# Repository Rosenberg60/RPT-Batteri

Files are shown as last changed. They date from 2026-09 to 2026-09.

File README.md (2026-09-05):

# RPT & Rosen Batterimonitor med Waveshare ESP32-S3-Touch-LCD-7 (Rev 1.2)

Dette projekt er en dedikeret CAN-bus monitor, telemetrilogger og web-dashboard for et **51,2V LiFePO₄ hybridsystem: Rosen 200Ah Master + RPT Tower 300Ah (Samlet 501 Ah / 25,6 kWh)** tilsluttet en **Deye SUN-12K-SG05LP3-EU** hybridinverter.

Systemet kører på en **Waveshare ESP32-S3-Touch-LCD-7 (Rev 1.2)** med 7,0" IPS RGB-skærm (800 × 480 capacitive touch), MicroSD-blackbox-logger og indbygget WiFi-webserver.

---

## 1. Systemstatus & Funktioner

* **Multi-Side Touch Dashboard (800 × 480 IPS)**:
  * **Side 1 (Hovedoversigt)**: Store hero-kort for **SOC (%)**, **Storage Power (kW)**, **Bank Spænding (V)** og **Total & Peak Strøm (A)** (med automatisk skalering for afladestrømme $> 100\text{ A}$). Statusfelter for Min/Max cellespænding, cell delta (mV), ladestatus, invertergrænser og intern 3,7V LiPo backup-batteristatus (`Lipo Bat: x.xV (xx%)`).
  * **Side 2 (Cell Diagnostics 32S)**: Komplet 32-celle visning med 16S Rosen Master og 16S RPT Tower. Dynamisk farvekodning (grøn/gul/rød/blå) og flimmerfri differential-opdatering.
  * **Side 3 (CAN Scanner)**: Real-tids tabel over alle modtagne CAN ID'er, frekvens, antal, payload og live frame-terminal.
  * **Touch Styring**: Touch er eksklusivt afgrænset til de 3 navigationsknapper i bunden ($Y \ge 420$) for at forhindre utilsigtede sideskift.
* **Integreret Web-Interface (WiFi)**:
  * Responsivt web-dashboard tilgåeligt via `http://rpt-batteri.local` eller ESP32's IP-adresse.
  * 4x forhøjede spændingssøjler for maksimal visualisering af cellebalance i 16S pack.
  * REST API endpoints: `/api/data` og `/api/scanner` med JSON telemetri.
* **Batteri Backup Monitor**:
  * Analog måling af tilsluttet 3,7V LiPo-batteri via GPIO 4 (ADC) med SOC estimering.
* **MicroSD Blackbox Logging**:
  * Automatisk logning af samtlige rå CAN-rammer til MicroSD i standard CSV-format (`/can_log_XXX.csv`).
* **Høj Stabilitet & Multi-Kerne Arkitektur**:
  * Dedikerede FreeRTOS tasks på Kerne 0 (CAN + Logger + WebServer) og Kerne 1 (UI Display Rendering).
  * Ikke-blokerende CAN queue drain, FreeRTOS mutexes i stedet for spinlocks, og beskyttelse mod Task Watchdog timeouts.

---

## 2. Systemarkitektur & Forbindelser

Inverteren (**Deye SUN-12K-SG05LP3-EU**) og batterierne (**Rosen 200Ah Master** og **RPT Tower 300Ah**) kommunikerer via batteriets BMS CAN-bus:

```text
+-----------------------------------------------------------------------------------------+
|                                    SYSTEMOVERSIGT                                       |
|                                                                                         |
|   +-----------------------+              CAN Bus            +-----------------------+   |
|   |  Deye SUN-12K         |<===============================>|  Rosen Master 200Ah   |   |
|   |  Inverter             |   (Eksisterende bus)            |  + RPT Tower 300Ah    |   |
|   +-----------------------+                                 +-----------+-----------+   |
|                                                                         |               |
|                                                     CAN-Port (RJ45)     |               |
|                                                     Pin 4 = CAN-H       |               |
|                                                     Pin 5 = CAN-L       |               |
|                                                                         v               |
|                                                             +-----------------------+   |
|                                                             |  Waveshare 7" Rev1.2  |   |
|                                                             |  ESP32-S3 (800x480)   |   |
|                                                             +-----------------------+   |
+-----------------------------------------------------------------------------------------+
```

---

## 3. Hardwareguide for Waveshare ESP32-S3-Touch-LCD-7 (Rev 1.2)

### Fysisk placering af stik og jumpere:

1. **Bunden af printet (Hvide JST-PH2.0 stik fra venstre mod højre)**:
   * `Battery` (2-ben): `-` (Venstre, GND), `+` (Højre, 3,7V LiPo/Li-ion).
   * `RS-485` (2-ben): `A`, `B`.
   * `I2C` (4-ben): **`VCC`**, **`GND`**, `SDA`, `SCL`.
   * `CAN` (2-ben): **`L`** (Venstre, CAN-L), **`H`** (Højre, CAN-H).
   * `Sensor AD` (3-ben): `3V3`, `GND`, `AD` (GPIO 4 ADC).
2. **Venstre side af printet (Gule jumpere)**:
   * Øverste gule jumper: `RS-485 120R / NC`.
   * Nederste gule jumper: **`CAN 120R / NC`** *(Skal sidde på `120R`)*.
3. **Midt-højre på printet (Sort 3-bens jumper)**:
   * Jumper mærket **`I2C 3V3 / 5V`** *(Sættes på `5V` hvis kortet forsynes via I2C-stikket)*.
4. **Toppen af printet**:
   * Venstre USB Type-C: `USB` (Native ESP32-S3 USB).
   * Højre USB Type-C: `UART1` (Onboard CH343 USB-to-UART programmeringsport).
   * MicroSD-kortlæser (TF-card).

---

## 4. CAN-forbindelse & Terminering

Fra et standard RJ45 netværkskabel forbundet til batteriets CAN-port:
* **Pin 4 (Blå leder)** $\rightarrow$ Forbindes til **`H`** (CAN-H) på Waveshare CAN-stikket.
* **Pin 5 (Blå/Hvid leder)** $\rightarrow$ Forbindes til **`L`** (CAN-L) på Waveshare CAN-stikket.
* Jumperen **`CAN 120R / NC`** skal sidde i **`120R`** position.

---

## 5. Softwarearkitektur

Kildekoden er struktureret modulært i `RPT_Batteri_Monitor/`:

```text
├── platformio.ini              # PlatformIO konfiguration (bygger direkte fra sketch-mappen)
├── RPT_Batteri_Monitor/        # [Arduino Sketch Mappe] - Åbnes i Arduino IDE eller PlatformIO
│   ├── RPT_Batteri_Monitor.ino # Hoved-sketch (setup, loop, task scheduling, CAN drain)
│   ├── board_config.h          # Pin-definitioner (CAN TX=20, RX=19, CH422G, I2C, SPI)
│   ├── board_battery.h/.cpp    # 3,7V LiPo spændingsmåling via ADC (GPIO 4)
│   ├── battery_data.h          # Komplette datastrukturer for 32S telemetri, limits & statistik
│   ├── can_receiver.h/.cpp     # TWAI driver med ringbuffer og alert-drevet RX
│   ├── deye_bms_decoder.h/.cpp # Deye/Rosen/RPT CAN protokol-dekoder med FreeRTOS mutex
│   ├── sd_logger.h/.cpp        # MicroSD CSV logger (flush hvert 1000ms / 50 rammer)
│   ├── ui.h/.cpp               # 800x480 PSRAM-framebuffer rendering, 3-siders UI & touch
│   ├── web_server.h/.cpp       # WiFi webserver, live dashboard og REST JSON endpoints
│   └── wifi_config.h           # WiFi SSID, adgangskode og værtsnavn
└── docs/
    ├── ESP32-S3-Touch-LCD-7-Sch.pdf   # Waveshare skematik
    └── waveshare_7_board_rev1.2.jpg   # Foto af printet med stikforklaringer
```

---

## 6. Kompilering & Upload

### Mulighed A: PlatformIO (Anbefalet)
1. Forbind kortet til PC via **UART1** USB-C porten (højre port).
2. Byg og upload med én kommando:
   ```bash
   pio run -t upload
   ```
3. Åbn seriel monitor ved 115200 baud:
   ```bash
   pio device monitor
   ```

### Mulighed B: Arduino IDE
1. Åbn filen: **`RPT_Batteri_Monitor/RPT_Batteri_Monitor.ino`** i Arduino IDE.
2. Vælg board: **ESP32S3 Dev Module**.
3. Under **Tools** vælges:
   * **Flash Size**: `16MB (128Mb)`
   * **Partition Scheme**: `16M Flash (3MB APP/9.9MB FATFS)` eller `Default 16MB`
   * **PSRAM**: `OPI PSRAM`
   * **CPU Frequency**: `240MHz`
   * **Upload Speed**: `921600`
   * **USB CDC On Boot**: `Disabled` (eller `Enabled`)
   * **Port**: Vælg COM-porten for USB-TO-UART forbindelsen (CH343 på UART1).
4. Klik på **Upload**.

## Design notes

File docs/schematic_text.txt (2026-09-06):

--- PAGE 1 ---
1
1
2
2
3
3
4
4
5
5
6
6
D D
C C
B B
A A
aveshareW
GND 41
GND 40
IO1 39
IO2 38
TXD0 37
RXD0 36
IO42 35
IO41 34
IO40 33
IO39 32
IO38 31
IO37 30
IO36 29
IO35 28
IO0 27
IO4526 IO4825 IO4724 IO2123 IO1422 IO1321 IO1220 IO1119 IO1018 IO917 IO4616 IO315
IO2014 IO1913 IO812 IO1811 IO1710 IO169 IO158 IO77 IO66 IO55 IO44 EN3 3V32 GND1
U8 ESP32-S3-WROOM-1-N8R8
3V3 GND
R1061KΩ A K
Red
PWR1
GND
3V3
IO3
GND
3V3
IO45
GND
3V3
IO46
Strapping Pins
I2C_VCC
G11
S22
G23 D2 4S1 5D1 6
M1
NDC7002N
D_SDA
SDA
3V3
I2C_VCC
D_SCL
R113
4.7K
SCL
3V3
R109
4.7K
R108
4.7K
R110
4.7K
GND
GND
RESET
3V3
IO4
IO5
IO6
IO7'
IO8
IO9
IO10
IO11
IO12 IO13
IO14
IO15
IO16
IO17
IO18
IO21
IO38
IO39
IO40
IO41
IO42
IO45
IO46
IO47
IO48
IO0
IO1
IO2
IO3
TX0
RX0
R107499R
ESP_RXD
GND
C46
100nF
GND
3V3
C45
10uF
ESP_USB_N
ESP_USB_P
ESP_TXD
1
2
3
H2
I2C_VCC
5V
3V3 I2C_VCC
GND
D_SDA
D_SCL
VCC
GND
SDA
SCL
C8
10uF/16V
C10
10uF/16V
GND
5V 3V3
C9
100nF
C11
100nF
G1
Vo2
Vi3
U5 SGM2212-3.3XKC3G/TR
GND A1/B12
VBUS A4/B9
CC1 A5
DN2 B7
DP1 A6
DN1 A7
SBU1 A8
GND A12/B1VBUS A9/B4CC2 B5
DP2 B6
SBU2 B8
GND MTB
Type_C1
USBD_N
USBD_P
USBD_N
USBD_P
GND VBUS
DCC1
DCC2
R2 5.1K
R3 5.1K
DCC1
DCC2 GND
GND
GND
CH_RXD
CH_TXD
VBUS
3V3
3V3
VBUS
KEY
K1
GND
R93 10K
3V3
DTR
RTS
IO0
DTR
RTS
3
1
2
Q9
SS8050
R4
10K
R29
10K
RESET
3
1
2
Q6
SS8050
C43 100nF
KEY
K2
GND
R100 10K
3V3
RESET
IO0
USB_P
USB_N
USBD_N
USBD_P
R5 0R
R10 0R
USB_N
USB_P
close to ENDPOINT
USBH_N
USBH_P
R65 0R
R66 0R
close to ENDPOINT
C30 100nF
GND
R8910K
R9010K
R9110K
GND
3V3
3V3
3V3
C42 10uF
R8810K
MOSI
SCK
MISO
SDCS
close to SD1
VBUS
R30 0.56Ω
C5
10uF/16V
GND
R31
4.7K
A KGreen
Led1
A K
RedLed2
R64
1.2K
GND GND
1 2 D12
1N5819
L2
4.7uH  4*4*1.8 1.7A
GND
C6
10uF/16V
GND
C7
10uF/16V
GND
VBAT
5V
C3
100nF
GND
1 2D11 1N5819
R44 0.56Ω
C4
100uF
Battery
USB  to UART
RO1
RE2
DE3
DI4 GND 5
A 6
B 7
VCC 8
U6
SP3485EN
5V
GND
GND
RS485_TX-
R82
10K
5V
C16 100nF
R73
10K
D15
SMAJ12CA
GND
RS485_TX+
1F1
1
F2
R70
120R
A1
COM2
B3
J4
C28
NC
C29
NC
A1
B1
EARTH
EARTH
S1
R76
4.7K
GND
R81
4.7K
3V3
R78
4.7K
R74
4.7K
GND
EARTH GND
R86 0R
RS485_TX-
RS485_TX+
RS485_TXD
RS485
USB
KEY
SD-CARD
CAN
GND
D8 LESD8LH5.0CT5G
D9
LESD8LH5.0CT5G
GND
GND
GND
D13 LESD8LH5.0CT5G
D14
LESD8LH5.0CT5G
GND
GND
D21
CD/D32
CMD3
VDD4
CLK5
VSS6
D07
D18
CD 9
GND10
SD1
GND
VOUT 1
CHRG2
STDBY4
PROG3
VCC5
BAT 6
GND0
LX 8
GND7
U4
CS8501
GND VBAT
11
22
00
J3
GND
R95
NC
R96
NC
R97
NC
R103
NC
R104
10K
R105
10K
C47
1uF
C48
100nF
GND
SDA
SCL
GND
3V3
EXIO2
EXIO1
EXIO3EXIO4
Sensor AD
IO19
IO20
D16
SMAJ12CA
D17
SMAJ12CA
VIO1
GND2
VDD53
TXD4
RXD5
V36
UD+7
UD-8 VBUS 9ACT# 10DCD 11DTRTNOW 12RTS 13DSR 14CTS 15RI 16
EP 0
U1
CH343P
默认贴3V3
High
Low
IO41
IO52
IO63
IO74
SCL5
SDA6
GND7
OC08 OC1 9OC2 10OC3 11IO0 12IO1 13VCC 14IO2 15IO3 16
U10
CH422G
TXD1
GND2
VCC3
RXD4 VIO 5CANL 6CANH 7S 8
U7
TJA1051T/3/1J
CANTX
CANRX
CANH
CANL
R92 0R
R98 0R
R99 0R
R101 0R
SGND
5V
R75
120R
A1 COM2 B3
J5
1
233
D18
SM24CANB
3V3
GND
R87 0R
SGNDSGND
C12
100nF
SGND
3V3
C15
100nF
SGND
5V
1
2
J6
1
2
J7
1
2
3
4
H1
GND
GND
R117
10K
3V3
D+1 D-2
GND3 HSD1- 4
HSD1+ 5
HSD2- 6
HSD2+ 7
OE8
VCC9
SEL10
U9
FSUSB42UMX
EXIO5
USB_SEL
RS485_RXD
C2
100nF
GND
VBUS
C1
10uF/16V
R77
0R
SGND
ESP_USB_N
ESP_USB_P
ESP_USBH_N
ESP_USBH_P
ESP_USBH_N
ESP_USBH_P
CANTX
CANRX
RS485_TXD
RS485_RXD
SDLCDWROOM-1/2
IO17
IO18
IO1
IO2
IO0
B6
B5
G3
R3
R4
EXIO1
EXIO2
EXIO3
EXIO4
DISP
CTP_RST
USB CAN Sensor
LCD_RST
USB_SEL
CANRX
CANTX
IO19
IO20
ESP_USB_N
ESP_USB_P
IO3 VSYNC
IO4
IO5
IO6
DE
AD
CTP_IRQ
IO7 PCLK
IO9
IO8 SDA
SCL
MOSI
MISO
SCK
SDCS
IO10
IO11
IO12
IO13
IO14 B3
IO21 G7
IO38 B4
IO39 G2
IO40 R7
IO41 R6
IO42 R5
GPIO43 ESP_TXD
GPIO44 ESP_RXD
IO45 G4
IO46 HSYNC
IO47
IO48 G5
G6
UART
IO15
IO16
RS485_TX
RS485_RX
B7
RTCN
RTCP
EXIO5
R111100R
R115 100R
R112 NC/100R
R114 100R
R116 100R
IO15
IO16
ESP32-S3-Touch-LCD-7 V1.2
1.2K   580mA
0.75K  900mA
0.68K  1000mA
5K   160mA
VUART
GND A1/B12
VBUS A4/B9
CC1 A5
DN2 B7
DP1 A6
DN1 A7
SBU1 A8
GND A12/B1VBUS A9/B4CC2 B5
DP2 B6
SBU2 B8
GND MTB
Type_C2
GND
CC1
CC2
USBH_N
USBH_P
USBH_N
USBH_P
R62 5.1K
R63 5.1K
CC1
CC2 GND
5V
R23
100K
R24
470K
GND GND
3
1
2Q7
MMBT3906
3
1
2
Q8
MMBT3906
3
1
2
Q5 AO3401
VUART
R67
100K
R68
470K
GND GND
3
1
2Q11
MMBT3906
3
1
2
Q12
MMBT3906
3
1
2
Q10AO3401
VUART 5V
VLED+ 1
VLED+ 2
VLED- 3
VLED- 4
GND 5
VCOM 6
DVDD 7
MODE 8
DE 9
VS 10
HS 11
B7 12
B6 13
B5 14
B4 15
B3 16
B2 17
B1 18
B0 19
G7 20
G6 21
G5 22
G4 23
G3 24
G2 25
G1 26
G0 27
R7 28
R6 29
R5 30
R4 31
R3 32
R2 33
R1 34
R0 35
GND 36
DCLK 37
GND 38
L/R 39
U/D 40
VGH 41
VGL 42
AVDD 43
RESET 44
NC 45
VCOM 46
DITHB 47
GND 48
NC 49
NC 50
51 51
52 52
J1
VLED+
VLED+
VLED-
VLED-
DE
DCLK
HSYNC
VSYNC
B3
B4
B5
B6
B7
R3
R4
R5
R6
R7
G2
G3
G4
G5
G6
G7
10k
R1
VCOM
VGH
VGL
AVDD_LCD
VCOM
0R7
0RR8
NCR6
NCR9
10kR11
NCR13
10kR12
CLK PCLK
HS
VS
100nF
C24
RST1
VDD2
GND3
INT4
SDA5
SCL6
00 7inch TOUCH (C)
J2
VLED-
10uH
L6
1
D6
1N5819
4.7K/NC
R21
1.8R
R25 1uF/25V
C25
VLED+
SW 1
GND2 FB 3
EN4 OV 5
IN 6
U3
AP3032
10uF
C26
1.6R/NC
R26
Backlight
LCD_VDD_EN
LCD_VDD
LCD_VDD
LCD_VDD
Panel_Voltage
10uF
C23
LCD_VDD
100K/NC
R22
104/25V
C27
0R/NC
R20
LCD_VDD
10k/NC
R50
100NF/NC
C34
68K/NC
R51
GND
0R/NC
R49
0R
R52BL_EN BL_EN_1
5.1K/0R/NC
R48
BL_EN_1
15K
R45
6.8k
R59 1uF/25V
C38
100nF
C37
13
2
10K
R58
NC
R56 VCOM
VCOM: 3.1V-5.3V
NC
R53SW 1
GND2
FB 3SHDN4
VIN5
U2
AP3012
22uH 4*4 ±20% 0.9A
L1
R54
10K
GNDC36
1uF
GND
1
D5
1N5819
4.7K
R57
33k
R55
C311uF
GND
104/50V
C32
GND
9.85V
AVDD_LCD
100nFC19
100nFC18
1
2
3
D3
BAT54S
1
2
3
D2
BAT54S
1uF/25V
C20
1uF/25V
C14
1K
R41
1K
R14
1 D1 BZT52C6V8S
10K
R15
100nF
C13
VGH
VGL
1
D4 BZT52C18S 47K
R42
1uF/25V
C22
16V
0R
R43
10uF/25V
C33
GND
100nF
C21
1uF/25V
C17
C39
10uF
LCD_RST
DISP
CTP_RST
CTP_SDA
CTP_SCL
CTP_IRQ
5V
EXIO6 LCD_VDD_EN
3V3
R16 100R
EXIO6
5V
C40 100nF
GND
LTVS16H5.0ET5GTVS1
LTVS16H5.0ET5GTVS2
SDA
SCL
CTP_SDA
CTP_SCL
UART
3V3
GND
GND
3V3
D+1 D-2
GND3 HSD1- 4
HSD1+ 5
HSD2- 6
HSD2+ 7
OE8
VCC9
SEL10
U13
FSUSB42UMX
UART_SEL
ESP_RXD
ESP_TXD
CH_RXD
CH_TXD
EX_RXD
EX_TXD
EX_RXD
EX_TXD
1
2
3
4
5
6
SW1
UART_SELUART_SEL
3V3
R17
10K
UART_H UART_H
3V3
AD
3V3
GND 1
2
3
J8
1
2
3
4
H3
GND GND
VBAT
R18
200K 1%
R19
100K 1%
GND
TP1
R27
100R
C35
NC
IO7'IO7
GND
PIC101
PIC102COC1PIC201
PIC202
COC2
PIC301
PIC302
COC3 PIC401
PIC402
COC4
PIC501
PIC502
COC5
PIC601
PIC602COC6
PIC701
PIC702
COC7
PIC801
PIC802
COC8
PIC901
PIC902
COC9
PIC1001
PIC1002
COC10
PIC1101
PIC1102
COC11
PIC1201
PIC1202COC12
PIC1301
PIC1302
COC13PIC1401
PIC1402
COC14
PIC1501
PIC1502COC15PIC1601PIC1602COC16
PIC1701
PIC1702
COC17
PIC1801PIC1802
COC18
PIC1901 PIC1902
COC19 PIC2001
PIC2002
COC20 PIC2101
PIC2102
COC21PIC2201
PIC2202
COC22
PIC2301
PIC2302
COC23
PIC2401
PIC2402
COC24
PIC2501
PIC2502COC25
PIC2601
PIC2602COC26 PIC2701
PIC2702COC27
PIC2801
PIC2802COC28
PIC2901
PIC2902COC29
PIC3001PIC3002
COC30
PIC3101
PIC3102
COC31
PIC3201
PIC3202COC32
PIC3301
PIC3302COC33
PIC3401
PIC3402COC34
PIC3501
PIC3502COC35
PIC3601
PIC3602
COC36
PIC3701
PIC3702
COC37PIC3801
PIC3802
COC38
PIC3901
PIC3902
COC39
PIC4001PIC4002
COC40
PIC4201PIC4202
COC42
PIC4301PIC4302
COC43
PIC4501
PIC4502COC45
PIC4601
PIC4602
COC46
PIC4701
PIC4702COC47
PIC4801
PIC4802COC48
PID101
PID102
COD1
PID201
PID202
PID203
COD2
PID301
PID302
PID303
COD3
PID401
PID402COD4
PID501 PID502
COD5
PID601 PID602
COD6
PID801 PID802
COD8
PID901 PID902
COD9
PID1101PID1102COD11
PID1201
PID1202COD12
PID1301 PID1302
COD13
PID1401 PID1402COD14
PID1501
PID1502
COD15
PID1601
PID1602
COD16
PID1701
PID1702
COD17
PID1801PID1802
PID1803
COD18
PIF101PIF102
COF1
PIF201PIF202
COF2
PIH101
PIH102
PIH103
PIH104
COH1
PIH201
PIH202
PIH203
COH2
PIH301
PIH302
PIH303
PIH304
COH3
PIJ101
PIJ102
PIJ103
PIJ104
PIJ105
PIJ106
PIJ107
PIJ108
PIJ109
PIJ1010
PIJ1011
PIJ1012
PIJ1013
PIJ1014
PIJ1015
PIJ1016
PIJ1017
PIJ1018
PIJ1019
PIJ1020
PIJ1021
PIJ1022
PIJ1023
PIJ1024
PIJ1025
PIJ1026
PIJ1027
PIJ1028
PIJ1029
PIJ1030
PIJ1031
PIJ1032
PIJ1033
PIJ1034
PIJ1035
PIJ1036
PIJ1037
PIJ1038
PIJ1039
PIJ1040
PIJ1041
PIJ1042
PIJ1043
PIJ1044
PIJ1045
PIJ1046
PIJ1047
PIJ1048
PIJ1049
PIJ1050
PIJ1051
PIJ1052
COJ1
PIJ200
PIJ201
PIJ202
PIJ203
PIJ204
PIJ205
PIJ206
COJ2
PIJ300PIJ301PIJ302
COJ3
PIJ401
PIJ402
PIJ403
COJ4
PIJ501
PIJ502
PIJ503
COJ5
PIJ601
PIJ602
COJ6
PIJ701
PIJ702
COJ7
PIJ801
PIJ802
PIJ803
COJ8
PIK101PIK102
COK1
PIK201 PIK202
COK2
PIL101 PIL102
COL1
PIL201 PIL202
COL2
PIL601 PIL602
COL6
PILed10A PILed10KCOLed1
PILed20A PILed20K
COLed2
COlogo1
PIM101
PIM102
PIM103 PIM104
PIM105
PIM106
COM1
PIP101
COP1
PIPWR10A PIPWR10K
COPWR1
PIQ501
PIQ502PIQ503
COQ5
PIQ601
PIQ602
PIQ603
COQ6
PIQ701
PIQ702
PIQ703
COQ7
PIQ801
PIQ802
PIQ803
COQ8
PIQ901
PIQ902
PIQ903
COQ9
PIQ1001
PIQ1002PIQ1003
COQ10
PIQ1101
PIQ1102
PIQ1103
COQ11
PIQ1201
PIQ1202
PIQ1203
COQ12
PIR101
PIR102COR1
PIR201PIR202COR2
PIR301PIR302
COR3
PIR401PIR402
COR4
PIR501PIR502COR5
PIR601 PIR602COR6
PIR701 PIR702
COR7
PIR801 PIR802COR8
PIR901 PIR902COR9
PIR1001PIR1002COR10
PIR1101PIR1102COR11
PIR1201 PIR1202COR12
PIR1301 PIR1302
COR13
PIR1401PIR1402
COR14
PIR1501
PIR1502
COR15
PIR1601PIR1602
COR16
PIR1701PIR1702
COR17
PIR1801
PIR1802COR18
PIR1901
PIR1902COR19
PIR2001PIR2002
COR20
PIR2101
PIR2102
COR21
PIR2201
PIR2202
COR22
PIR2301
PIR2302
COR23
PIR2401
PIR2402
COR24
PIR2501
PIR2502COR25
PIR2601
PIR2602COR26
PIR2701 PIR2702
COR27
PIR2901PIR2902
COR29
PIR3001PIR3002
COR30
PIR3101
PIR3102
COR31
PIR4101PIR4102
COR41
PIR4201
PIR4202
COR42
PIR4301
PIR4302
COR43
PIR4401PIR4402
COR44
PIR4501
PIR4502COR45
PIR4801
PIR4802COR48
PIR4901 PIR4902
COR49
PIR5001 PIR5002
COR50
PIR5101 PIR5102
COR51
PIR5201PIR5202
COR52PIR5301PIR5302
COR53
PIR5401
PIR5402
COR54
PIR5501
PIR5502COR55
PIR5601
PIR5602COR56
PIR5701
PIR5702COR57
PIR5801
PIR5802
PIR5803
COR58
PIR5901
PIR5902COR59
PIR6201PIR6202COR62
PIR6301PIR6302
COR63
PIR6401
PIR6402COR64
PIR6501PIR6502COR65
PIR6601PIR6602
COR66
PIR6701
PIR6702
COR67
PIR6801
PIR6802
COR68
PIR7001
PIR7002COR70
PIR7301
PIR7302
COR73
PIR7401PIR7402
COR74
PIR7501
PIR7502COR75
PIR7601
PIR7602
COR76
PIR7701
PIR7702
COR77
PIR7801
PIR7802COR78
PIR8101PIR8102
COR81
PIR8201
PIR8202COR82
PIR8601PIR8602COR86
PIR8701PIR8702
COR87
PIR8801
PIR8802COR88
PIR8901
PIR8902COR89
PIR9001
PIR9002COR90PIR9101
PIR9102
COR91
PIR9201PIR9202
COR92
PIR9301PIR9302
COR93
PIR9501
PIR9502
COR95PIR9601
PIR9602
COR96PIR9701
PIR9702
COR97
PIR9801PIR9802
COR98
PIR9901PIR9902
COR99
PIR10001PIR10002
COR100
PIR10101PIR10102
COR101
PIR10301
PIR10302
COR103PIR10401
PIR10402
COR104PIR10501
PIR10502
COR105
PIR10601PIR10602
COR106
PIR10701PIR10702
COR107
PIR10801
PIR10802
COR108PIR10901
PIR10902
COR109 PIR11001
PIR11002
COR110
PIR11101PIR11102
COR111
PIR11201PIR11202COR112 PIR11301
PIR11302
COR113
PIR11401PIR11402
COR114
PIR11501PIR11502
COR115
PIR11601PIR11602
COR116
PIR11701
PIR11702
COR117
PIS101
PIS102
PIS103
COS1
PISD101
PISD102
PISD103
PISD104
PISD105
PISD106
PISD107
PISD108
PISD109
PISD1010
COSD1
PISW101
PISW102
PISW103
PISW104
PISW105
PISW106
COSW1
PITP101
COTP1
PITVS101PITVS102
COTVS1
PITVS201PITVS202
COTVS2
PIType0C10A10B12
PIType0C10A40B9
PIType0C10A5
PIType0C10A6
PIType0C10A7
PIType0C10A8
PIType0C10A90B4
PIType0C10A120B1
PIType0C10B5
PIType0C10B6
PIType0C10B7
PIType0C10B8
PIType0C10MTB
COType0C1
PIType0C20A10B12
PIType0C20A40B9
PIType0C20A5
PIType0C20A6
PIType0C20A7
PIType0C20A8
PIType0C20A90B4
PIType0C20A120B1
PIType0C20B5
PIType0C20B6
PIType0C20B7
PIType0C20B8
PIType0C20MTB
COType0C2
PIU100
PIU101
PIU102
PIU103
PIU104
PIU105
PIU106
PIU107
PIU108 PIU109
PIU1010
PIU1011
PIU1012
PIU1013
PIU1014
PIU1015
PIU1016
COU1
PIU201
PIU202
PIU203PIU204
PIU205
COU2
PIU301
PIU302 PIU303
PIU304 PIU305
PIU306
COU3
PIU400
PIU401
PIU402
PIU403
PIU404
PIU405
PIU406
PIU407
PIU408
COU4
PIU501PIU502PIU503
COU5
PIU601
PIU602
PIU603
PIU604 PIU605
PIU606
PIU607
PIU608
COU6
PIU701
PIU702
PIU703
PIU704 PIU705
PIU706
PIU707
PIU708
COU7
PIU801
PIU802
PIU803
PIU804
PIU805
PIU806
PIU807
PIU808
PIU809
PIU8010
PIU8011
PIU8012
PIU8013
PIU8014
PIU8015PIU8016PIU8017PIU8018PIU8019PIU8020PIU8021PIU8022PIU8023PIU8024PIU8025PIU8026
PIU8027
PIU8028
PIU8029
PIU8030
PIU8031
PIU8032
PIU8033
PIU8034
PIU8035
PIU8036
PIU8037
PIU8038
PIU8039
PIU8040
PIU8041
COU8
PIU901
PIU902
PIU903
PIU904
PIU905
PIU906
PIU907
PIU908
PIU909
PIU9010
COU9
PIU1001
PIU1002
PIU1003
PIU1004
PIU1005
PIU1006
PIU1007
PIU1008 PIU1009
PIU10010
PIU10011
PIU10012
PIU10013
PIU10014
PIU10015
PIU10016
COU10
PIU1301
PIU1302
PIU1303
PIU1304
PIU1305
PIU1306
PIU1307
PIU1308
PIU1309
PIU13010
COU13
PIC1002PIC1102
PIC1202
PIC2302PIC2402
PIC3002
PIC4002
PIC4202
PIC4502PIC4602
PIC4701PIC4801
PIH201
PIH301
PIJ202
PIJ801
PIR1701
PIR2002
PIR7401
PIR7601PIR7802
PIR8802PIR8902PIR9002PIR9101
PIR9302
PIR9501PIR9601PIR9701
PIR10002
PIR10601
PIR10901PIR11001
PISD104
PIU101
PIU106
PIU502
PIU705
PIU802
PIU909
PIU10014
PIU1309
NL3V3
PIC302PIC402
PIC802PIC902
PIC1502
PIC1602
PIC2602
PIC2901
PID1102
PID1202
PIH203
PIL601
PIQ1002
PIQ1202
PIR2101
PIR4301
PIR8201
PITVS201
PIType0C20A40B9
PIType0C20A90B4
PIU306
PIU401
PIU503
PIU608
PIU703NL5V
PIC2902
PID1602
PID1701
PIF202
PIJ402
PIR8202
PIU606
NLA1
PIJ803
PIU806
NLADNLIO6
PIC3101PIC3202PIC3302
PID301
PID502
PIJ1043
PIR4502
PIR5502
NLAVDD0LCD
PIC2801PID1502
PID1601
PIF102
PIR7001
PIR7301
PIU607
NLB1
PIJ1016
PIU8022
NLB3NLIO14
PIJ1015
PIU8031
NLB4NLIO38
PIJ1014
PIU8011
NLB5NLIO18
PIJ1013
PIU8010
NLB6NLIO17
PIJ1012
PIU8018
NLB7NLIO10
PIP101
PIR4901
PIR5201NLBL0EN
PID1801
PIJ602
PIR7501
PIU707
NLCANH
PID1802
PIJ503
PIJ601PIU706NLCANL
PIU704
PIU906 NLCANRX
PIU701
PIU907
NLCANTX
PIR6202
PIType0C20A5
NLCC1
PIR6302PIType0C20B5
NLCC2
PIU104
PIU1305
NLCH0RXD
PIU105
PIU1304
NLCH0TXD
PIJ204
PIU804
NLCTP0IRQNLIO4
PIJ201
PIR11601
NLCTP0RSTNLEXIO1
PIH104
PIM102
PIR11302NLD0SCL
PIH103
PIM105
PIR10802
NLD0SDA
PIR202
PIType0C10A5 NLDCC1
PIR302
PIType0C10B5
NLDCC2
PIJ109
PIU805
NLDENLIO5
PIR2102
PIR2201
PIR5202
PIR11401
PIU304
NLBL0EN01
NLDISPNLEXIO2
PIQ902
PIR402
PIU1012NLDTR
PID1501
PID1702
PIR8602
PIU8036
PIU1301NLESP0RXD
NLRX0
PIR10701
PIU1302
NLESP0TXD
PIU8013
PIU902NLESP0USB0N
PIU8014
PIU901NLESP0USB0P
PIR6501
PIU904 NLESP0USBH0N
PIR6601
PIU905 NLESP0USBH0P
PIH303
PIU1307 NLEX0RXD
PIH304
PIU1306 NLEX0TXD
PIJ1044 PIR1101
PIR11201
NLEXIO3NLLCD0RST
PIR9202
PIR11102
NLEXIO4 NLSDCS
PIR11502
PIR11701
PIU9010
NLEXIO5 NLUSB0SEL
PIR1602
PIR5401 PIU204
NLEXIO6NLLCD0VDD0EN
PIJ1025
PIU8032
NLG2NLIO39
PIJ1024
PIK201
PIQ903
PIR10001
PIU8027
NLG3NLIO0
PIJ1023
PIR9602
PIR10401
PIU8026
NLG4NLIO45
PIJ1022
PIU8025 NLG5NLIO48
PIJ1021
PIU8024
NLG6NLIO47
PIJ1020
PIU8023
NLG7NLIO21
PIC101PIC202
PIC301PIC401
PIC501
PIC601PIC701
PIC801PIC901 PIC1001PIC1101
PIC1302PIC1402
PIC1601
PIC1702
PIC2002 PIC2102PIC2202
PIC2301PIC2401
PIC2501
PIC2601
PIC2701
PIC2802
PIC3001
PIC3102PIC3201PIC3301
PIC3401
PIC3501
PIC3602
PIC3702PIC3802
PIC3902
PIC4001
PIC4201
PIC4301
PIC4501PIC4601
PIC4702PIC4802
PID102
PID202
PID401
PID802
PID902
PID1302
PID1402
PIH102
PIH302
PIJ105
PIJ1017
PIJ1018
PIJ1019
PIJ1026
PIJ1027
PIJ1033
PIJ1034
PIJ1035
PIJ1036
PIJ1038
PIJ1048
PIJ1051
PIJ1052
PIJ200
PIJ203
PIJ300PIJ301
PIJ802
PIK101
PIK202
PIPWR10K
PIR201
PIR301
PIR602
PIR902
PIR1202
PIR1502
PIR1901
PIR2202
PIR2302 PIR2402
PIR2501PIR2601
PIR4202
PIR5402 PIR5701
PIR5901
PIR6201
PIR6301
PIR6401
PIR6702 PIR6802
PIR7302
PIR8601
PIR8701
PIR10302PIR10402PIR10502
PIR11702
PIS102
PISD106
PISD109
PISD1010
PISW101 PISW104
PITVS102
PITVS202
PIType0C10A10B12
PIType0C10A120B1
PIType0C10MTB
PIType0C20A10B12
PIType0C20A120B1
PIType0C20MTB
PIU100
PIU102
PIU202
PIU302
PIU400PIU407
PIU501
PIU604 PIU605
PIU801 PIU8040
PIU8041
PIU903
PIU908
PIU1007
PIU1303
PIU1308
NLGND
PIJ1011
PIR9702
PIR10501
PIU8016
NLHS
NLHSYNCNLIO46
PIH101
PIH202
PIM101
PIM103
PIR10801
PIR11301
NLI2C0VCC
PIJ1032
PIU8039
NLIO1 NLR3
PIJ1031
PIU8038
NLIO2 NLR4
PIJ1010
PIR9502
PIR10301
PIU8015
NLIO3
NLVS
NLVSYNC
PIC3502
PIJ1037
PIR2701
NLCLKNLDCLK
NLIO7 NLPCLK
PIR2702
PIU807NLIO7'
PIJ205
PIM106
PIR10902
PIU8012
PIU1006
NLCTP0SDA
NLIO8 NLSDA
PIJ206
PIM104
PIR11002 PIU8017
PIU1005
NLCTP0SCL
NLIO9 NLSCL
PIR9802
PIU8019
NLIO11 NLMOSI
PIR9902
PIU8020
NLIO12 NLSCK
PIR10102
PIU8021
NLIO13 NLMISO
PIR7402 PIU601
PIU808
NLIO15NLRS4850TXD
PIR7801
PIR8101
PIU809
NLIO16NLRS4850RXD
PIJ1028
PIU8033
NLIO40 NLR7
PIJ1029
PIU8034
NLIO41 NLR6
PIJ1030
PIU8035
NLIO42 NLR5
PIJ107
PIR102
PIR702
PIR802
PIR1102
PIR1302
PIR2001
PIC502
PIR3001
PIR3102
PIR4401
PIU405
PIC1401
PID201
PIR1402
PIC1801
PIC1901
PID501PIL102
PIU201
PIC1802PID203
PIC1902 PID303
PIC2001
PID302 PIR4102
PIC3402
PIR5002PIR5101
PIC3601PIC3901
PIL101
PIR4302
PIU205
PID601
PIL602
PIU301
PID1201
PIL201PIU408
PIJ108
PIR101
PIJ1039
PIR601
PIR701
PIJ1040 PIR801
PIR901
PIJ1045
PIJ1047
PIR1201
PIR1301
PIJ1049
PIJ1050
PIJ401
PIJ403
PIR7002
PIJ501
PIJ502
PIR7502
PILed10A
PILed20APIR3101
PILed10KPIU402
PILed20KPIU404
PIPWR10APIR10602
PIQ501
PIQ803PIR2401
PIQ601PIR401
PIQ701
PIQ703
PIQ801
PIR2301
PIQ901PIR2901
PIQ1001
PIQ1203PIR6801
PIQ1101
PIQ1103
PIQ1201
PIR6701
PIR1601PIU1003
PIR1801
PIR1902
PITP101
PIR4501PIR5302
PIR5602
PIR5801
PIR4802
PIR5102
PIU303
PIR4902 PIR5001
PIR5501PIR5702PIU203
PIR5601PIR5803
PIR5902
PIR6402PIU403
PIR7602
PIS103
PIU602
PIU603 PIR7702
PIU708
PIR8102PIS101
PIR8801
PIR9201 PISD102
PIR8901
PIR9801 PISD103
PIR9001
PIR9901 PISD105
PIR9102
PIR10101 PISD107
PIR11101PIU1001 PIR11202PIU10016
PIR11402PIU10015PIR11501PIU1002
PIR11602PIU10013
PISD101
PISD108
PIType0C10A8
PIType0C10B8
PIType0C20A8
PIType0C20B8
PIU1010
PIU1011
PIU1014
PIU1015
PIU1016
PIU8028
PIU8029
PIU8030
PIU1004
PIU1008 PIU1009
PIU10010
PIU10011
PIU10012
PIC4302
PIK102
PIQ603
PIR9301
PIU803
NLRESET
PIF201
PIJ701
NLRS4850TX0
PIF101
PIJ702NLRS4850TX0
PIQ602
PIR2902
PIU1013
NLRTS
PIC1201 PIC1501
PID1803
PIR7701
PIR8702
PIU702
NLSGND
PIR10702PIU8037NLTX0
PIR1702 PISW103 PISW106NLUART0H
PISW102 PISW105
PIU13010
NLUART0SEL
PIR501
PIU108NLUSB0N
PIR1001
PIU107NLUSB0P
PID801
PIR502
PIType0C10A7
PIType0C10B7
NLUSBD0N
PID901
PIR1002
PIType0C10A6
PIType0C10B6 NLUSBD0P
PID1301
PIR6502
PIType0C20A7
PIType0C20B7
NLUSBH0N
PID1401
PIR6602
PIType0C20A6
PIType0C20B6 NLUSBH0P
PIC602PIC702
PIJ302
PIL202
PIR1802
PIU406
PIC102PIC201
PID1101
PIQ502
PIQ802
PIR3002
PIR4402
PIU103
PIU109NLVBUS
PIC3701PIC3801
PIJ106
PIJ1046
PIR5301
PIR5802 NLVCOM
PIC2101PIC2201PID402
PIJ1041
PIR4101
PIR4201
NLVGH
PIC1301PIC1701PID101
PIJ1042
PIR1401
PIR1501
NLVGL
PIC2502PIC2702
PID602
PIJ101
PIJ102
PIU305
NLVLED0
PIJ103
PIJ104
PIR2502PIR2602PIR4801
NLVLED0
PIQ503
PIQ702
PIQ1003
PIQ1102
PITVS101PIType0C10A40B9
PIType0C10A90B4
NLVUART--- PAGE 2 ---
PAC101PAC102COC1
PAC201PAC202COC2
PAC302PAC301COC3
PAC402PAC401COC4
PAC501PAC502COC5
PAC602PAC601
COC6
PAC702
PAC701COC7
PAC802
PAC801COC8PAC902
PAC901
COC9
PAC1002
PAC1001COC10PAC1102
PAC1101COC11
PAC1201PAC1202COC12
PAC1302PAC1301COC13
PAC1401PAC1402COC14
PAC1502PAC1501COC15
PAC1602PAC1601
COC16
PAC1701PAC1702COC17
PAC1802PAC1801COC18PAC1902PAC1901COC19
PAC2001PAC2002COC20
PAC2102PAC2101COC21
PAC2201PAC2202COC22
PAC2302
PAC2301COC23PAC2401
PAC2402
COC24
PAC2501
PAC2502COC25
PAC2602PAC2601COC26
PAC2701PAC2702COC27
PAC2802
PAC2801COC28
PAC2902
PAC2901COC29
PAC3002
PAC3001
COC30
PAC3101PAC3102COC31
PAC3201PAC3202COC32 PAC3302PAC3301COC33
PAC3402PAC3401COC34
PAC3502PAC3501
COC35
PAC3601PAC3602COC36
PAC3702
PAC3701
COC37
PAC3801
PAC3802COC38
PAC3901PAC3902COC39
PAC4002PAC4001COC40
PAC4202PAC4201COC42
PAC4302PAC4301
COC43PAC4502PAC4501COC45
PAC4602PAC4601COC46
PAC4702PAC4701COC47
PAC4802PAC4801COC48
PAD101PAD102COD1
PAD203
PAD202PAD201
COD2
PAD303
PAD302PAD301
COD3
PAD401PAD402COD4
PAD502
PAD501
COD5
PAD602
PAD601COD6
PAD802
PAD801COD8
PAD902
PAD901COD9
PAD1102PAD1101COD11
PAD1202
PAD1201
COD12
PAD1302
PAD1301COD13
PAD1402
PAD1401
COD14
PAD1502
PAD1501
COD15
PAD1602
PAD1601
COD16
PAD1702PAD1701COD17
PAD1803
PAD1802
PAD1801
COD18
PAF102
PAF101
COF1
PAF202
PAF201
COF2
PAH101
PAH102
PAH103
PAH104
COH1
PAH203PAH202PAH201COH2
PAH304
PAH303
PAH302
PAH301
COH3
PAJ101PAJ102PAJ103PAJ104PAJ105PAJ106PAJ107PAJ108PAJ109PAJ1012PAJ1010PAJ1011PAJ1013PAJ1014PAJ1015PAJ1016PAJ1017PAJ1018PAJ1019PAJ1020PAJ1021PAJ1022PAJ1023PAJ1024PAJ1025PAJ1026PAJ1027PAJ1028PAJ1029PAJ1030PAJ1031PAJ1032PAJ1033PAJ1034PAJ1035PAJ1036PAJ1037PAJ1038PAJ1039PAJ1040
PAJ1052 PAJ1051
PAJ1050PAJ1049PAJ1048PAJ1047PAJ1046PAJ1045PAJ1044PAJ1043PAJ1042PAJ1041
COJ1
PAJ200
PAJ206PAJ205PAJ204PAJ203PAJ202PAJ201
COJ2
PAJ301
PAJ300
PAJ302
COJ3
PAJ403PAJ401PAJ402
COJ4
PAJ503PAJ501PAJ502
COJ5
PAJ601
PAJ602
COJ6
PAJ701
PAJ702
COJ7
PAJ803
PAJ802
PAJ801
COJ8
PAK102PAK101
COK1
PAK202PAK201
COK2
PAL101
PAL102
COL1
PAL201PAL202COL2
PAL602
PAL601
COL6
PALed10KPALed10ACOLed1
PALed20KPALed20ACOLed2
COlogo1
PAM101
PAM102
PAM103PAM104
PAM105
PAM106
COM1
PAP101COP1
PAPWR10KPAPWR10ACOPWR1
PAQ503
PAQ502PAQ501
COQ5
PAQ603
PAQ602PAQ601
COQ6
PAQ703
PAQ702PAQ701
COQ7
PAQ803
PAQ802PAQ801
COQ8
PAQ903
PAQ902PAQ901
COQ9
PAQ1003
PAQ1002PAQ1001
COQ10
PAQ1103
PAQ1102PAQ1101
COQ11
PAQ1203
PAQ1202PAQ1201
COQ12
PAR101PAR102COR1
PAR202PAR201COR2
PAR302PAR301COR3
PAR402PAR401COR4PAR502PAR501COR5
PAR602PAR601COR6
PAR702PAR701COR7
PAR802PAR801COR8
PAR902PAR901COR9
PAR1002PAR1001COR10
PAR1102PAR1101COR11
PAR1202PAR1201COR12
PAR1302PAR1301COR13
PAR1401PAR1402COR14
PAR1501PAR1502COR15
PAR1602PAR1601COR16
PAR1701PAR1702COR17
PAR1802PAR1801COR18
PAR1902PAR1901COR19
PAR2002PAR2001COR20
PAR2101PAR2102COR21
PAR2201PAR2202COR22
PAR2302PAR2301COR23
PAR2402PAR2401COR24
PAR2502
PAR2501COR25PAR2602
PAR2601COR26
PAR2702PAR2701COR27
PAR2902PAR2901COR29
PAR3002
PAR3001
COR30
PAR3102PAR3101COR31
PAR4101PAR4102COR41
PAR4201PAR4202COR42
PAR4301PAR4302COR43
PAR4402
PAR4401
COR44
PAR4501PAR4502COR45PAR4802PAR4801COR48
PAR4902PAR4901COR49
PAR5002PAR5001COR50
PAR5102PAR5101COR51
PAR5202PAR5201COR52
PAR5302
PAR5301COR53
PAR5402PAR5401COR54
PAR5502
PAR5501COR55
PAR5602PAR5601COR56
PAR5702
PAR5701
COR57
PAR5802
PAR5803PAR5801
COR58
PAR5902
PAR5901COR59
PAR6202PAR6201COR62
PAR6302PAR6301COR63
PAR6402PAR6401COR64
PAR6501PAR6502COR65
PAR6601PAR6602COR66
PAR6702PAR6701COR67
PAR6802PAR6801COR68
PAR7002
PAR7001
COR70
PAR7302
PAR7301COR73PAR7402
PAR7401
COR74
PAR7502PAR7501COR75
PAR7602
PAR7601COR76
PAR7702PAR7701COR77
PAR7802
PAR7801
COR78PAR8102
PAR8101
COR81
PAR8202
PAR8201COR82
PAR8602
PAR8601
COR86
PAR8702PAR8701COR87
PAR8802
PAR8801COR88PAR8902
PAR8901COR89
PAR9002PAR9001COR90
PAR9102PAR9101COR91
PAR9202
PAR9201COR92
PAR9302PAR9301COR93
PAR9502PAR9501COR95
PAR9602PAR9601COR96
PAR9702PAR9701COR97
PAR9802
PAR9801COR98
PAR9902PAR9901COR99
PAR10002PAR10001COR100
PAR10102PAR10101COR101
PAR10302PAR10301COR103
PAR10402PAR10401COR104
PAR10502PAR10501COR105
PAR10602PAR10601COR106
PAR10702PAR10701COR107
PAR10802PAR10801COR108
PAR10902
PAR10901COR109
PAR11002
PAR11001COR110
PAR11102PAR11101COR111
PAR11202PAR11201COR112
PAR11302PAR11301COR113
PAR11402PAR11401COR114
PAR11502PAR11501COR115
PAR11602PAR11601COR116
PAR11702PAR11701COR117
PAS103
PAS102
PAS101
COS1
PASD100
PASD1010PASD109PASD108PASD107PASD106PASD105PASD104PASD103PASD102PASD101
COSD1
PASW101PASW102PASW103
PASW106PASW105PASW104
COSW1
PATP101COTP1
PATVS102PATVS101COTVS1
PATVS202PATVS201COTVS2
PAType0C10MTB
PAType0C102
PAType0C10B6
PAType0C10A40B9
PAType0C10A90B4
PAType0C10A120B1
PAType0C10A10B12
PAType0C10B8
PAType0C10A5
PAType0C10B5
PAType0C10A8
PAType0C10A7
PAType0C10B7
PAType0C10A6
COType0C1
PAType0C20MTB
PAType0C202
PAType0C20B6
PAType0C20A40B9
PAType0C20A90B4
PAType0C20A120B1
PAType0C20A10B12
PAType0C20B8
PAType0C20A5
PAType0C20B5
PAType0C20A8
PAType0C20A7
PAType0C20B7
PAType0C20A6COType0C2
PAU1016
PAU1015
PAU1014
PAU1013
PAU101PAU102PAU103PAU104
PAU105
PAU1010PAU1011
PAU106
PAU107
PAU108
PAU109
PAU100
PAU1012
COU1
PAU204PAU205
PAU202PAU203PAU201
COU2
PAU301PAU302PAU303
PAU306PAU305PAU304
COU3
PAU405PAU406PAU407PAU408
PAU404PAU403PAU402PAU401
PAU400COU4
PAU502
PAU503
PAU501
COU5
PAU601
PAU602
PAU603
PAU604
PAU608
PAU607
PAU606
PAU605
COU6
PAU701
PAU702
PAU703
PAU704
PAU708
PAU707
PAU706
PAU705
COU7
PAU8041
PAU8040
PAU8039
PAU8038
PAU8037
PAU8036
PAU8035
PAU8034
PAU8033
PAU8032
PAU8031
PAU8030
PAU8029
PAU8028
PAU8027
PAU8026PAU8025PAU8024PAU8023PAU8022PAU8021PAU8020PAU8019PAU8018PAU8017PAU8016PAU8015
PAU8014
PAU8013
PAU8012
PAU8011
PAU8010
PAU809
PAU808
PAU807
PAU806
PAU805
PAU804
PAU803
PAU802
PAU801
COU8
PAU902PAU901
PAU905
PAU904PAU9010PAU909
PAU908
PAU903
PAU906PAU907COU9
PAU1001
PAU1002
PAU1003
PAU1004
PAU1005
PAU1006
PAU1007
PAU1008
PAU10016
PAU10015
PAU10014
PAU10013
PAU10012
PAU10011
PAU10010
PAU1009
COU10
PAU1301PAU1302
PAU13010
PAU1309
PAU1308
PAU1303
PAU1304
PAU1305PAU1306PAU1307COU13
PAC1002
PAC1102PAC1202PAC2302PAC2402
PAC3002PAC4002PAC4202PAC4502PAC4602PAC4701PAC4801
PAH201
PAH301
PAJ202
PAJ801
PAR1701
PAR2002
PAR7401PAR7601PAR7802PAR8802PAR8902PAR9002PAR9101PAR9302PAR9501PAR9601PAR9701PAR10002PAR10601PAR10901PAR11001
PASD104
PAU101
PAU106
PAU502
PAU705
PAU802
PAU909
PAU10014
PAU1309
PAC302
PAC402
PAC802PAC902PAC1502PAC1602
PAC2602
PAC2901
PAD1102PAD1202
PAH203
PAL601
PAQ1002PAQ1202
PAR2101PAR4301
PAR8201
PATVS201
PAType0C20A40B9
PAType0C20A90B4
PAU306
PAU401
PAU503
PAU608
PAU703
PAC2902
PAD1602PAD1701
PAF202
PAJ402
PAR8202
PAU606
PAJ803
PAU806
PAC3101
PAC3202 PAC3302
PAD301
PAD502
PAJ1043
PAR4502PAR5502
PAC2801
PAD1502PAD1601
PAF102PAR7001
PAR7301
PAU607
PAJ1016
PAU8022
PAJ1015
PAU8031
PAJ1014
PAU8011
PAJ1013
PAU8010
PAJ1012
PAU8018
PAP101
PAR4901PAR5201PAR2102PAR2201PAR5202
PAR11401
PAU304
PAD1801
PAJ602
PAR7501
PAU707
PAD1802
PAJ503
PAJ601
PAU706
PAU704
PAU906
PAU701
PAU907
PAR6202
PAType0C20A5
PAR6302
PAType0C20B5
PAU104
PAU1305
PAU105
PAU1304
PAC3502
PAJ1037
PAR2701
PAJ204
PAU804
PAJ201
PAR11601
PAJ206
PAM104
PAR11002
PAU8017
PAU1005
PAJ205
PAM106
PAR10902
PAU8012
PAU1006
PAH104
PAM102
PAR11302
PAH103
PAM105
PAR10802PAR202
PAType0C10A5
PAR302
PAType0C10B5
PAJ109
PAU805
PAQ902
PAR402
PAU1012
PAD1501PAD1702
PAR8602
PAU8036
PAU1301
PAR10701
PAU1302
PAU8013
PAU902
PAU8014
PAU901
PAR6501
PAU904
PAR6601
PAU905
PAH303
PAU1307
PAH304
PAU1306
PAJ1044
PAR1101
PAR11201PAR9202PAR11102PAR11502PAR11701
PAU9010
PAR1602
PAR5401 PAU204
PAJ1025
PAU8032
PAJ1024
PAK201
PAQ903
PAR10001
PAU8027
PAJ1023
PAR9602PAR10401
PAU8026
PAJ1022
PAU8025
PAJ1021
PAU8024
PAJ1020
PAU8023
PAC101PAC202PAC301
PAC401
PAC501
PAC601PAC701PAC801PAC901PAC1001
PAC1101
PAC1302
PAC1402
PAC1601
PAC1702PAC2002
PAC2102
PAC2202PAC2301PAC2401PAC2501
PAC2601
PAC2701
PAC2802PAC3001
PAC3102
PAC3201 PAC3301PAC3401PAC3501
PAC3602
PAC3702
PAC3802PAC3902
PAC4001PAC4201PAC4301PAC4501PAC4601PAC4702PAC4802
PAD102 PAD202PAD401
PAD802PAD902PAD1302PAD1402
PAH102PAH302
PAJ105PAJ1017PAJ1018PAJ1019PAJ1026PAJ1027PAJ1033PAJ1034PAJ1035PAJ1036PAJ1038PAJ1048
PAJ1051PAJ1052
PAJ200
PAJ203
PAJ300
PAJ301
PAJ802
PAK101PAK202
PAPWR10K
PAR201PAR301
PAR602PAR902PAR1202PAR1502
PAR1901
PAR2202
PAR2302PAR2402
PAR2501PAR2601
PAR4202PAR5402PAR5701PAR5901
PAR6201PAR6301PAR6401PAR6702PAR6802PAR7302PAR8601PAR8701PAR10302PAR10402PAR10502PAR11702
PAS102
PASD106PASD109PASD1010
PASW101
PASW104
PATVS102PATVS202
PAType0C10A10B12
PAType0C10A120B1
PAType0C10MTB
PAType0C20A10B12
PAType0C20A120B1
PAType0C20MTB
PAU100
PAU102
PAU202
PAU302
PAU400
PAU407
PAU501
PAU604 PAU605
PAU801PAU8040
PAU8041
PAU903
PAU908
PAU1007
PAU1303
PAU1308
PAJ1011
PAR9702PAR10501
PAU8016
PAH101
PAH202
PAM101
PAM103
PAR10801PAR11301
PAJ1032
PAU8039
PAJ1031
PAU8038
PAJ1010
PAR9502PAR10301
PAU8015
PAR2702PAU807PAR9802
PAU8019
PAR9902
PAU8020
PAR10102
PAU8021
PAR7402
PAU601
PAU808
PAR7801PAR8101
PAU809
PAJ1028
PAU8033
PAJ1029
PAU8034
PAJ1030
PAU8035
PAJ107
PAR102PAR702PAR802PAR1102PAR1302PAR2001
PAC502
PAR3001
PAR3102
PAR4401
PAU405
PAC1401
PAD201
PAR1402
PAC1801PAC1901
PAD501
PAL102PAU201
PAC1802
PAD203
PAC1902
PAD303
PAC2001
PAD302
PAR4102
PAC3402
PAR5002PAR5101
PAC3601PAC3901
PAL101PAR4302 PAU205PAD601
PAL602
PAU301
PAD1201
PAL201
PAU408
PAJ108
PAR101
PAJ1039
PAR601PAR701
PAJ1040
PAR801PAR901
PAJ1047
PAR1201PAR1301
PAJ403
PAR7002
PAJ502
PAR7502
PALed10APALed20A
PAR3101
PALed10K
PAU402
PALed20K
PAU404
PAPWR10A
PAR10602
PAQ501
PAQ803
PAR2401
PAQ601
PAR401
PAQ701
PAQ703
PAQ801
PAR2301
PAQ901
PAR2901
PAQ1001
PAQ1203
PAR6801
PAQ1101
PAQ1103
PAQ1201
PAR6701PAR1601
PAU1003
PAR1801PAR1902
PATP101
PAR4501PAR5302PAR5602
PAR5801
PAR4802PAR5102PAU303 PAR4902PAR5001PAR5501PAR5702
PAU203
PAR5601
PAR5803
PAR5902
PAR6402
PAU403
PAR7602
PAS103
PAU602
PAU603
PAR7702
PAU708
PAR8102
PAS101
PAR8801PAR9201
PASD102
PAR8901PAR9801
PASD103
PAR9001PAR9901
PASD105
PAR9102PAR10101
PASD107
PAR11101
PAU1001
PAR11202
PAU10016
PAR11402
PAU10015
PAR11501
PAU1002
PAR11602
PAU10013
PAC4302
PAK102
PAQ603
PAR9301
PAU803
PAF201
PAJ701
PAF101
PAJ702
PAQ602
PAR2902
PAU1013
PAC1201
PAC1501
PAD1803
PAR7701PAR8702
PAU702
PAR10702
PAU8037
PAR1702
PASW103
PASW106
PASW102
PASW105
PAU13010
PAR501
PAU108
PAR1001
PAU107
PAD801
PAR502
PAType0C10A7
PAType0C10B7
PAD901
PAR1002
PAType0C10A6
PAType0C10B6
PAD1301
PAR6502
PAType0C20A7
PAType0C20B7
PAD1401
PAR6602
PAType0C20A6
PAType0C20B6
PAC602PAC702
PAJ302
PAL202
PAR1802
PAU406
PAC102PAC201
PAD1101
PAQ502PAQ802
PAR3002PAR4402
PAU103
PAU109
PAC3701
PAC3801
PAJ106 PAJ1046
PAR5301
PAR5802 PAC2101
PAC2201
PAD402
PAJ1041
PAR4101PAR4201
PAC1301
PAC1701
PAD101
PAJ1042
PAR1401PAR1501
PAC2502
PAC2702
PAD602
PAJ101PAJ102
PAU305
PAJ103PAJ104
PAR2502PAR2602
PAR4801
PAQ503
PAQ702
PAQ1003
PAQ1102
PATVS101
PAType0C10A40B9
PAType0C10A90B4

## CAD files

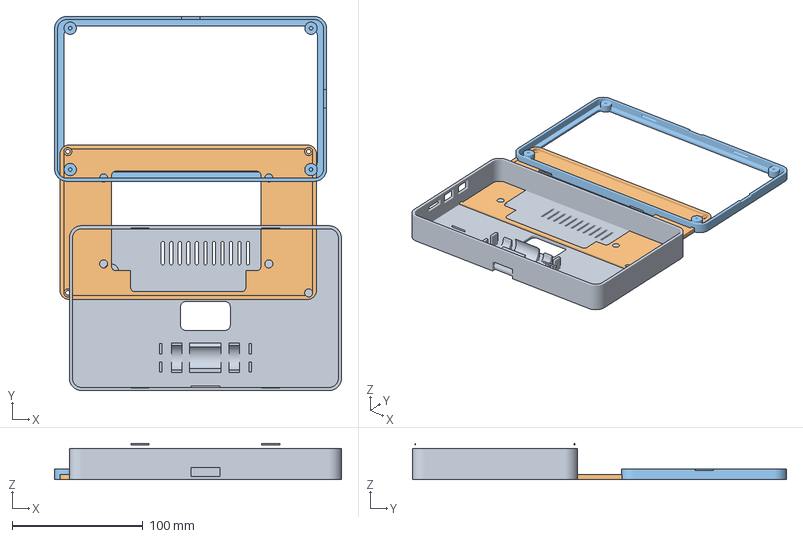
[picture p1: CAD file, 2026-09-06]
3D_Print_Case/Waveshare7_Back_Case version 5.3mf
219.3 x 285.9 x 27.8 mm
Waveshare7_Back_Case.stl
Waveshare7_Mellemstykke.stl
Waveshare7_Front_Bezel.stl

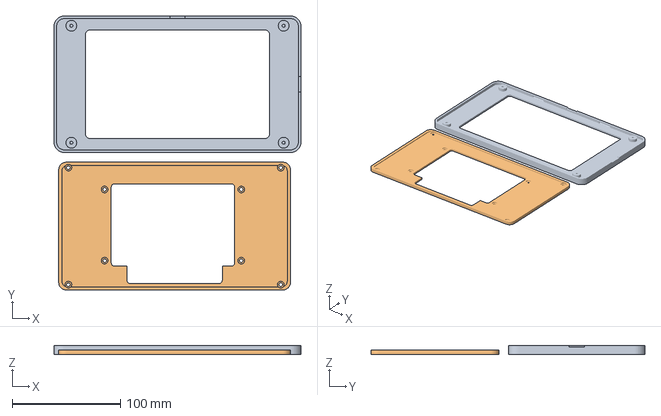
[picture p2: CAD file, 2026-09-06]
3D_Print_Case/Waveshare7_Back_Case FINAL top og mellem.3mf
228.0 x 252.9 x 8.00 mm
Waveshare7_Front_Bezel.stl
Waveshare7_Mellemstykke.stl

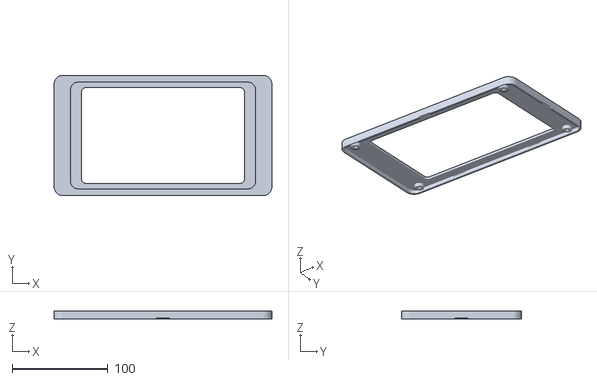
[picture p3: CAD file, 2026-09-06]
3D_Print_Case/Waveshare7_Front_Bezel.stl
228.0 x 126.0 x 8.00

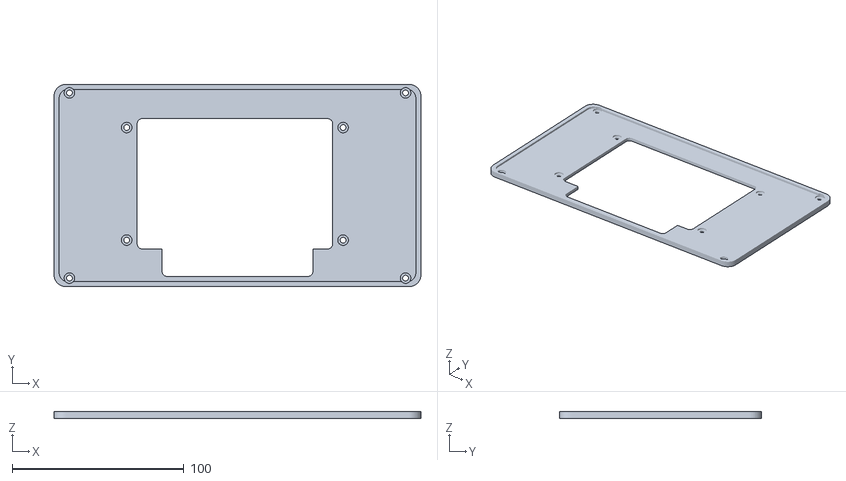
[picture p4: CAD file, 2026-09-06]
3D_Print_Case/Waveshare7_Mellemstykke.stl
214.0 x 118.0 x 4.00

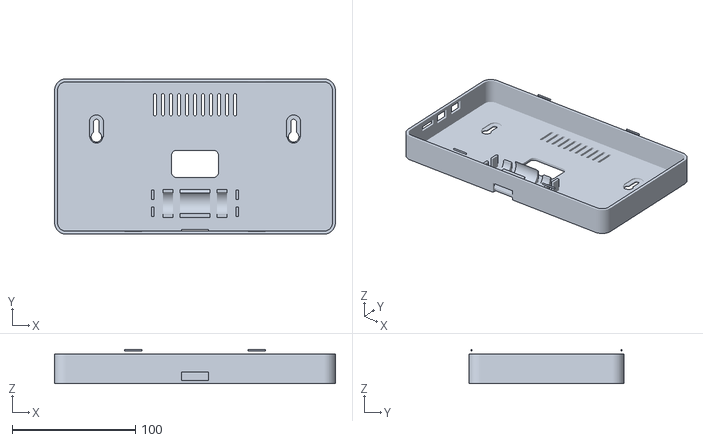
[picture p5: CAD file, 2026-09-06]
3D_Print_Case/Waveshare7_Back_Case.stl
228.0 x 126.0 x 27.8

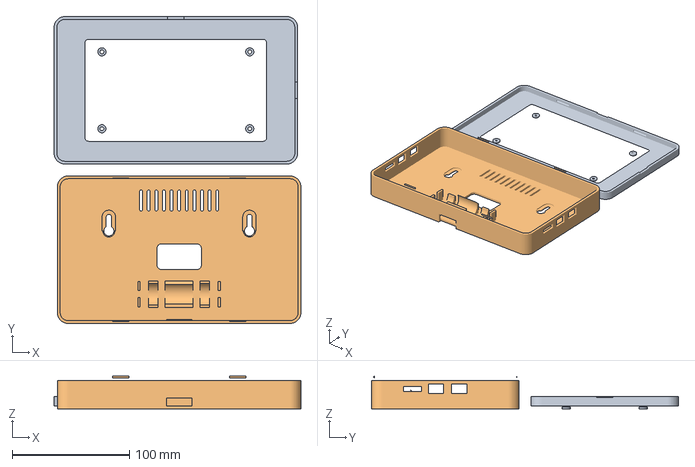
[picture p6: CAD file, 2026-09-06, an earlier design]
3D_Print_Case/Waveshare7_Back_Case version 2.3mf
210.8 x 262.1 x 27.8 mm
Waveshare7_Front_Bezel.stl
Waveshare7_Back_Case.stl

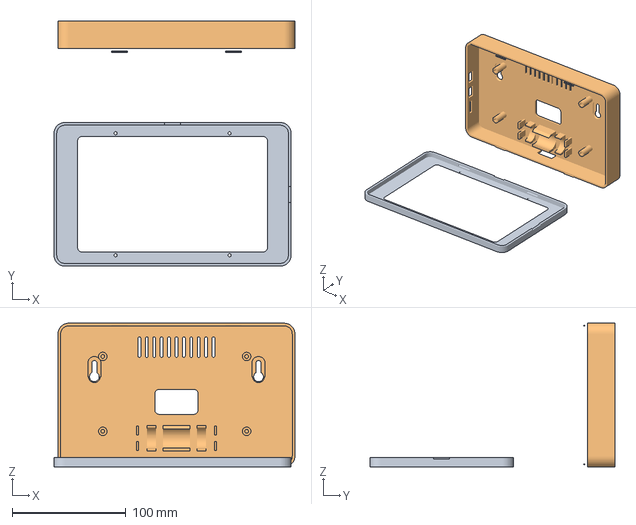
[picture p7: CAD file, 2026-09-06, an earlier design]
3D_Print_Case/Waveshare7_Back_Case version 3.3mf
211.4 x 215.1 x 126.0 mm
Waveshare7_Front_Bezel.stl
Waveshare7_Back_Case.stl

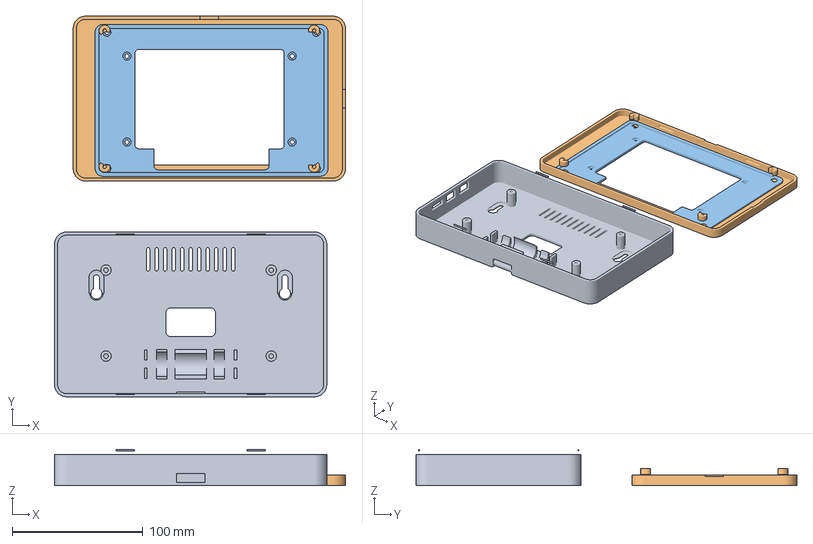
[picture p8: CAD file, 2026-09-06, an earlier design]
3D_Print_Case/Waveshare7_Back_Case version 4.3mf
222.3 x 290.8 x 27.8 mm
Waveshare7_Back_Case.stl
Waveshare7_Front_Bezel.stl
Waveshare7_Mellemstykke.stl

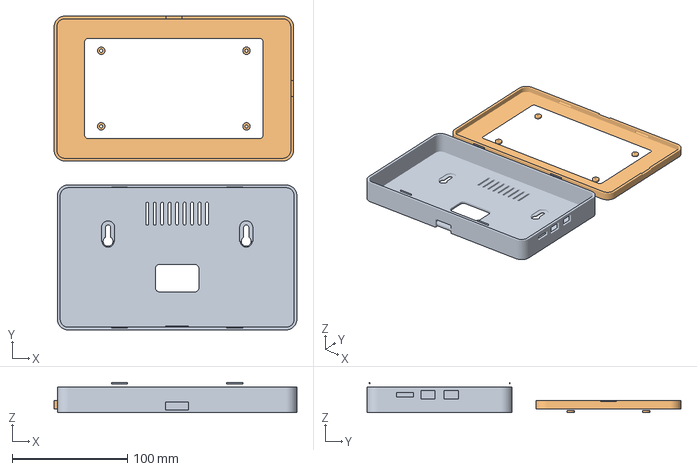
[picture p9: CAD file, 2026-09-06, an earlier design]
3D_Print_Case/Waveshare7_Back_Case version 1.3mf
210.9 x 272.7 x 26.3 mm
Waveshare7_Back_Case.stl
Waveshare7_Front_Bezel.stl

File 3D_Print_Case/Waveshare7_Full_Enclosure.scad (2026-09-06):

// =============================================================================
// PARAMETRIC WALL-MOUNT ENCLOSURE FOR WAVESHARE ESP32-S3-TOUCH-LCD-7 (REV 1.2)
// Designed for Bambu Lab 3D Printers (Bambu Studio / Bambu P1S / X1C / A1 / H2D)
// -----------------------------------------------------------------------------
// Features:
// 1. Flush Sunken Front Bezel (glass is 100% plant / flush with front face)
// 2. Snap-Fit tool-free closure with 2x pry-slots for easy disassembly
// 3. Integrated 18650 Li-ion / LiPo snap-in battery cradle in bottom of case
// 4. Port cutouts (2x USB-C + MicroSD TF card) on both right and left sides
// 5. Wall-mount keyhole slots on back (horizontal spacing 120mm)
// 6. Rear and bottom cable feedthroughs + cooling ventilation slots
// 7. 4x M3 mounting boss posts inside front bezel matching Waveshare factory studs
// =============================================================================

/* [Render Mode] */
part = "both"; // [both, front, back]
exploded_distance = 45;

/* [Display Specifications (Waveshare 7.0" Touch)] */
glass_w        = 192.96;
glass_h        = 110.76;
glass_r        = 7.88;
glass_pocket_d = 2.0;     // Recess depth so touch glass is 100% flush with bezel face
active_w       = 155.0;
active_h       = 87.0;
glass_clearance= 0.45;    // Fit clearance per side (0.9mm total W/H)

// 4x Waveshare Factory M3 brass standoffs on back of LCD (from official drawing)
// Horizontal distance 126.20mm, vertical 65.65mm, shifted by -1.53mm in X relative to glass
ws_standoff_x1 = -64.63;
ws_standoff_x2 =  61.57;
ws_standoff_y1 =  33.80;
ws_standoff_y2 = -31.85;

// Front bezel internal clamp boss positions (anchored to top & bottom perimeter walls)
bezel_boss_y_top =  53.5;
bezel_boss_y_bot = -53.5;
bezel_boss_x_dist = 100.0; // Spacing: X = +/- 50mm

// LCD metal chassis body size behind the glass
lcd_body_w     = 166.5;   // Clearance for 164.9mm LCD chassis
lcd_body_h     = 101.5;   // Clearance for 100.0mm LCD chassis

/* [18650 Battery Cradle Specs] */
bat_d             = 18.6;   // 18650 cell diameter (+ clearance)
bat_r             = bat_d / 2;
bat_len           = 66.5;   // Length clearance for 18650 cell
bat_y_pos         = -38.0;  // Position in bottom half of back case

/* [Enclosure Dimensions] */
wall           = 2.4;
outer_w        = 228.0;   // 228mm (+20mm wider for plenty of internal USB plug room)
outer_h        = 126.0;
corner_r       = 9.5;
total_depth    = 32.0;    // 32mm total depth (plenty of room for 18650 + CAN wiring)
front_depth    = 8.0;     // Front bezel rim depth
back_depth     = total_depth - front_depth; // 24.0mm
lip_height     = 4.5;
snap_depth     = 0.75;

$fn = 48;

module rounded_rect(w, h, r) {
    hull() {
        translate([-w/2 + r, -h/2 + r]) circle(r=r);
        translate([ w/2 - r, -h/2 + r]) circle(r=r);
        translate([-w/2 + r,  h/2 - r]) circle(r=r);
        translate([ w/2 - r,  h/2 - r]) circle(r=r);
    }
}

module rounded_box(w, h, d, r) {
    linear_extrude(height=d) {
        rounded_rect(w, h, r);
    }
}

module keyhole_slot() {
    union() {
        translate([0, -6, -0.5])
            cylinder(d=8.5, h=wall + 2);
        translate([-4.5/2, -6, -0.5])
            cube([4.5, 12, wall + 2]);
        translate([0, 6, -0.5])
            cylinder(d=4.5, h=wall + 2);
        translate([0, -6, wall - 1.2])
            cylinder(d1=8.5, d2=11.5, h=2);
        translate([-11.5/2, -6, wall - 1.2])
            cube([11.5, 12, 2]);
        translate([0, 6, wall - 1.2])
            cylinder(d=11.5, h=2);
    }
}

// 18650 Snap-in Battery Cradle with Central Snap Clamp
module battery_18650_holder() {
    cradle_wall = 2.0;
    snap_w = 24.0;
    overlap = 0.3; // Overlap with floor ensures clean 2-manifold union

    translate([0, bat_y_pos, wall - overlap]) {
        // 1. Central Snap Clamp with flexible C-arms
        difference() {
            translate([-snap_w/2, -(bat_r + cradle_wall), 0])
                cube([snap_w, (bat_r + cradle_wall)*2, bat_r + 4.5 + overlap]);

            // Cylindrical battery bed
            translate([-snap_w/2 - 1, 0, bat_r + overlap])
                rotate([0, 90, 0])
                    cylinder(r=bat_r, h=snap_w + 2, $fn=64);

            // Top snap entry throat (16.6mm wide, flexes open over 18.6mm cell)
            translate([-snap_w/2 - 1, -8.3, bat_r + overlap + 1.8])
                cube([snap_w + 2, 16.6, 12]);

            // 45-degree lead-in ramps on top lip for smooth press-fit insertion
            translate([-snap_w/2 - 1, -8.3, bat_r + overlap + 4.5])
                rotate([45, 0, 0])
                    cube([snap_w + 2, 6, 6]);
            translate([-snap_w/2 - 1, 8.3, bat_r + overlap + 4.5])
                rotate([-45, 0, 0])
                    cube([snap_w + 2, 6, 6]);
        }

        // 2. End-stop walls with wire pass-through notches
        for (sx = [-1, 1]) {
            translate([sx * (bat_len/2 + 1.0), 0, 0]) {
                difference() {
                    translate([-1.0, -(bat_r + 1.5), 0])
                        cube([2.0, (bat_r + 1.5)*2, bat_r + 2.0 + overlap]);
                    // Wire pass-through notch at center for battery leads
                    translate([-2.0, -3.0, overlap])
                        cube([4.0, 6.0, bat_r + 3.0]);
                }
            }
        }

        // 3. Side cradle support saddles near both ends
        for (sx = [-22, 22]) {
            translate([sx - 4, 0, 0]) {
                difference() {
                    translate([0, -(bat_r + cradle_wall), 0])
                        cube([8, (bat_r + cradle_wall)*2, bat_r + overlap]);
                    translate([-1, 0, bat_r + overlap])
                        rotate([0, 90, 0])
                            cylinder(r=bat_r, h=10, $fn=64);
                }
            }
        }
    }
}

// Front bezel internal mounting bosses for Mellemstykke (well away from the 170x100 cutout)
mid_mount_x = 98.0; // Spacing: X = +/- 98mm (in the wide 228mm enclosure)
mid_mount_y = 54.0; // Spacing: Y = +/- 54mm

// =============================================================================
// 1. FRONT BEZEL (FLUSH SUNKEN DISPLAY + SOLID SHELF + 170x100 CUTOUT + BOSSES)
// =============================================================================
module front_bezel() {
    pw = glass_w + 2 * glass_clearance; // 193.86mm
    ph = glass_h + 2 * glass_clearance; // 111.66mm
    pr = glass_r + glass_clearance;

    // Shelf geometry:
    // Front face is at Z = front_depth (8.0mm)
    // Glass pocket drops by 1.8mm -> shelf floor is at Z = 6.2mm
    // Shelf is 2.5mm thick -> internal cavity stops at Z = 3.7mm
    // Bosses extend from Z = 3.7mm down to Z = 0 (height = 3.7mm)
    shelf_floor_z   = front_depth - glass_pocket_d; // 6.2mm
    shelf_thickness = 2.5;                           // 2.5mm thick solid continuous ledge!
    cavity_ceil_z   = shelf_floor_z - shelf_thickness; // 3.7mm

    union() {
        difference() {
            rounded_box(outer_w, outer_h, front_depth, corner_r);

            // 1. Flush Sunken Glass Pocket (1.8mm deep from front face, down to Z = 6.2mm)
            translate([0, 0, shelf_floor_z])
                linear_extrude(height=glass_pocket_d + 1)
                    rounded_rect(pw, ph, pr);

            // 2. LCD Metal Body Pass-Through Cutout: EXACTLY 170mm x 100mm (Through the shelf)
            translate([0, 0, -1])
                linear_extrude(height=front_depth + 2)
                    rounded_rect(170.0, 100.0, 4.0);

            // 3. Internal cavity hollow (STOPS at Z = 3.7mm to GUARANTEE 2.5mm solid shelf!)
            translate([0, 0, -0.5])
                linear_extrude(height=cavity_ceil_z + 0.5)
                    rounded_rect(outer_w - 2 * wall, outer_h - 2 * wall, corner_r - wall);

            // 4. Snap-fit female retention grooves (inside top & bottom walls)
            for (sy = [-1, 1]) {
                for (sx = [-50, 50]) {
                    translate([sx, sy * (outer_h / 2 - wall + 0.1), 2.5])
                        rotate([0, 90, 0])
                            cylinder(r=0.9, h=16, center=true);
                }
            }

            // 5. Pry Slots (2x on bottom and side edges for tool-free disassembly)
            translate([0, -outer_h/2, 0])
                cube([14, wall * 2, 2.0], center=true);
            translate([outer_w/2, 0, 0])
                cube([wall * 2, 14, 2.0], center=true);
        }
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

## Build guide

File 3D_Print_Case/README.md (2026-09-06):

# 3D Print Enclosure - Waveshare ESP32-S3-Touch-LCD-7 (Rev 1.2)
Bredde udvidet til **228 mm** (20 mm ekstra bredde for masser af fri plads til USB-stik og kabler indvendigt).

## De 3 Færdige STL-filer:

1. **`Waveshare7_Front_Bezel.stl` (Frontramme - 228 mm bred)**
   - **1.8 mm forsænket lomme (undersænkning)**: Måler 193.9 mm x 111.7 mm, hvor Waveshare touch-glasset lægges i forfra og flugter 100% plant med rammen.
   - **Solid 2.5 mm tyk støttehylde**: 11.9 mm bred i siderne og 5.8 mm i top/bund, som glasset hviler stabilt på.
   - **Hul til metal-displaykasse**: Nøjagtigt **170.0 mm x 100.0 mm**.
   - **4x massive indvendige hjørnebøsninger** (X = ±98 mm, Y = ±54 mm) til Mellemstykket: Vokser direkte ud af frontvæggen/hylden.
   - Orienteret med fronten opad, så undersænkningen ses direkte i Bambu Studio.

2. **`Waveshare7_Mellemstykke.stl` (Mellemstykke / Display Carrier)**
   - **4x indvendige huller**: Skrues direkte i Waveshares 4 fabriksmonterede M3 messingbøsninger (X = -64.63 / +61.57 mm, Y = +33.80 / -31.85 mm).
   - **4x ydre hjørnehuller**: Skrues fast i frontrammens 4 hjørnebøsninger (X = ±98 mm, Y = ±54 mm).
   - **Stor center-åbning**: Fuld adgang til ESP32-S3 printkort, stik og knapper.
   - **Udvidet venstre udskæring (44 mm bred)**: Giver masser af fri plads til indvendige USB-C stik og kabler.
   - **Bund-udskæring**: God plads til batteriledninger.

3. **`Waveshare7_Back_Case.stl` (Bunden / Bagkasse - 228 mm bred)**
   - **Helt ren og flad bund**: De 4 stag er helt fjernet, så der er masser af plads til ledningsføring.
   - **Integreret 18650 snap-holder**: Med fleksible C-klemmer i bunden.
   - **Porte kun i venstre side**: 2x USB-C + 1x MicroSD (højre side er 100% lukket).
   - **Vægmontering**: 2x nøglehuller med 160 mm afstand.
   - **Kabelgennemføringer**: Central åbning bagpå til vægdåse + knockout-rille i bunden.
   - **Snap-fit lukning** med åbningsriller.

---

## Samlevejledning:
1. Skru `Waveshare7_Mellemstykke.stl` fast bag på Waveshare-displayet med 4x korte M3-skruer ind i displayets egne gevind.
2. Læg samlingen i `Waveshare7_Front_Bezel.stl` og skru 4x M3-skruer gennem mellemstykkets ydre huller ned i frontrammens bøsninger. Glasset ligger nu plant i den 1.8 mm dybe undersænkning foran.
3. Isæt 18650-batteriet i bunden af bagkassen, forbind kablerne (nu med 20 mm ekstra bredde til USB-stik), og klik kassen sammen.

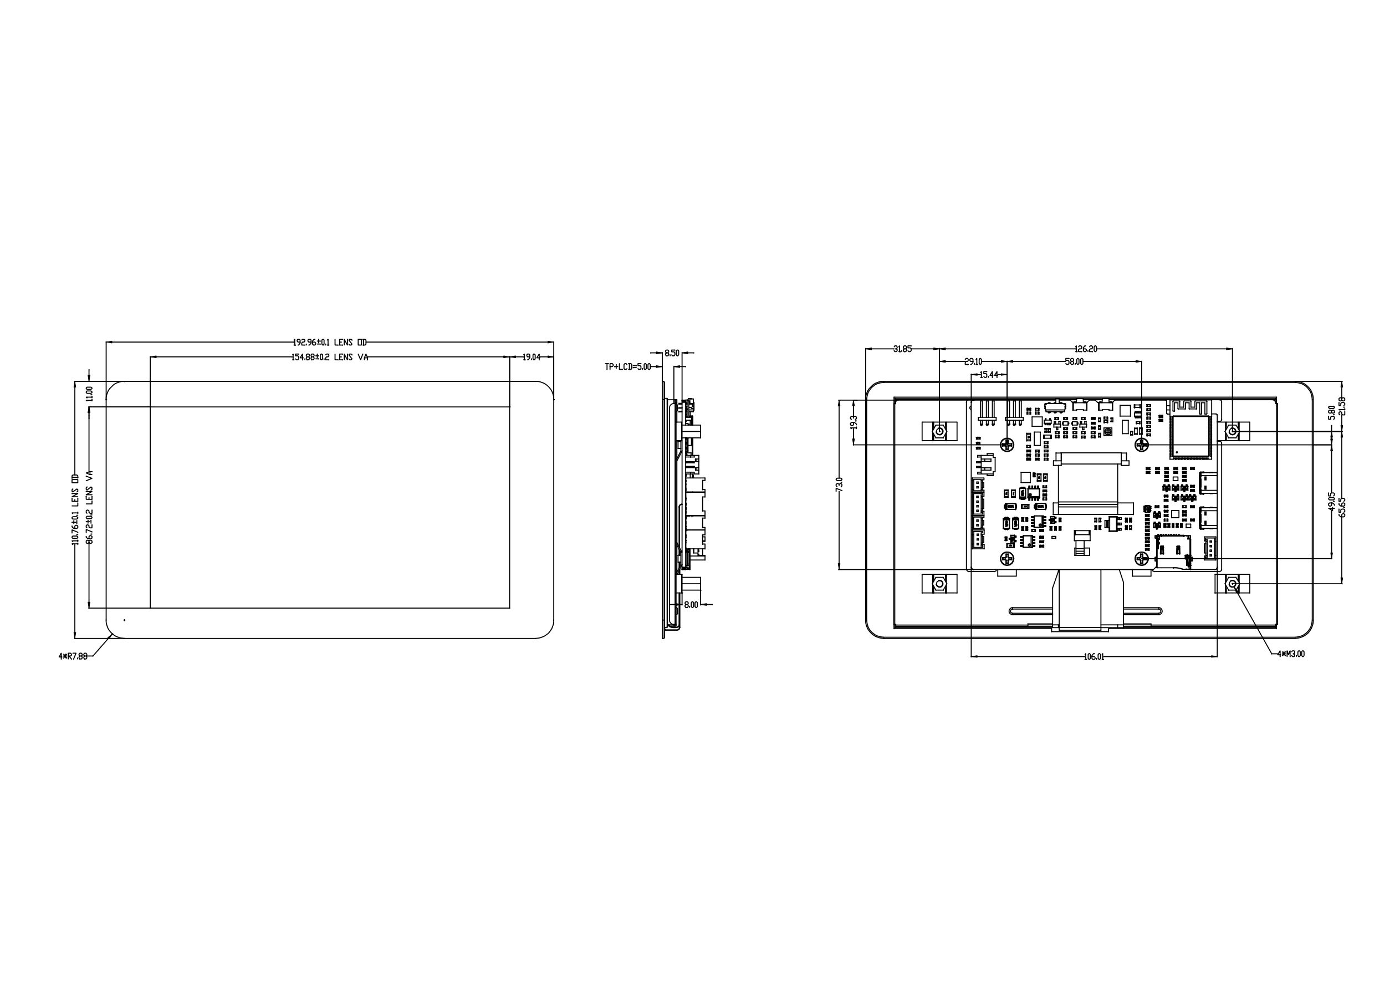
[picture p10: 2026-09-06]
3D_Print_Case/drawing_highres.png

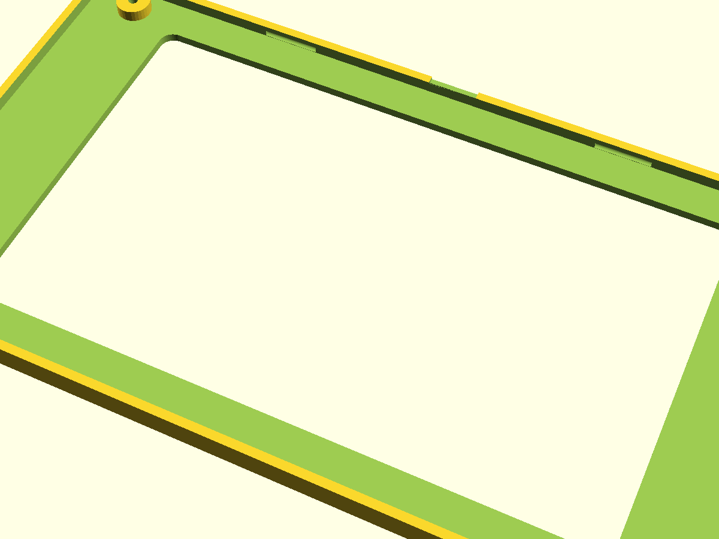
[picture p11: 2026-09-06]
3D_Print_Case/front_outside_view2.png

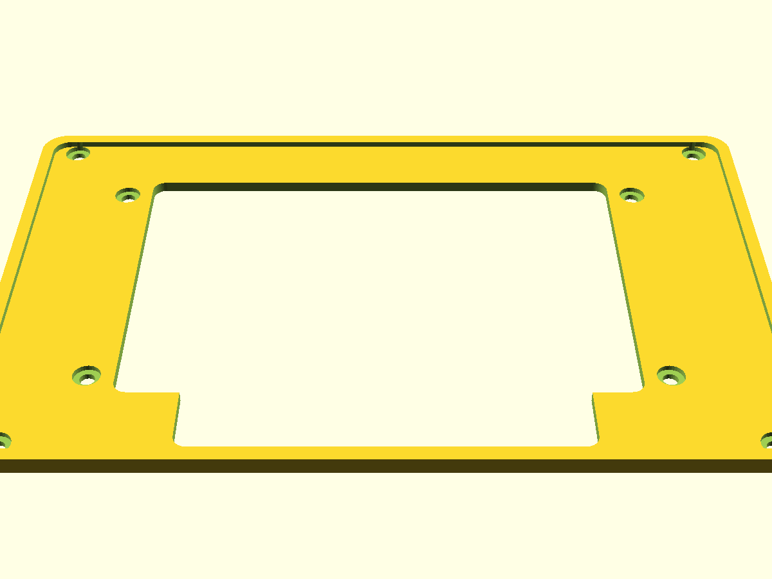
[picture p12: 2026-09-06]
3D_Print_Case/mellemstykke_full.png

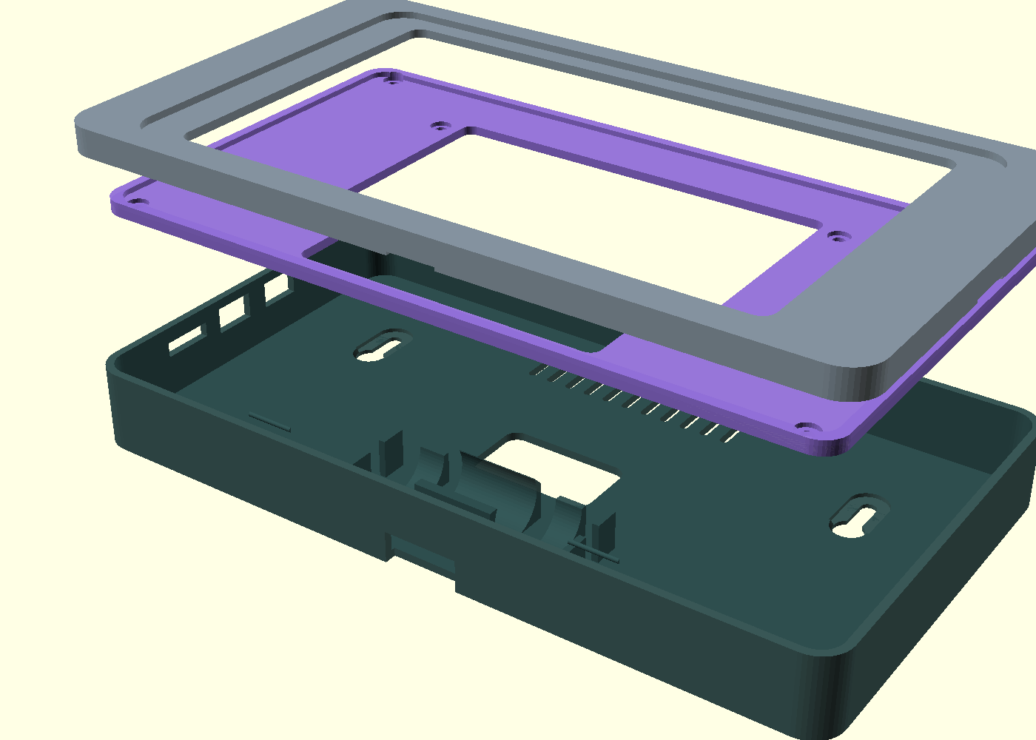
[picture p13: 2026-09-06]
3D_Print_Case/enclosure_228mm_exploded.png

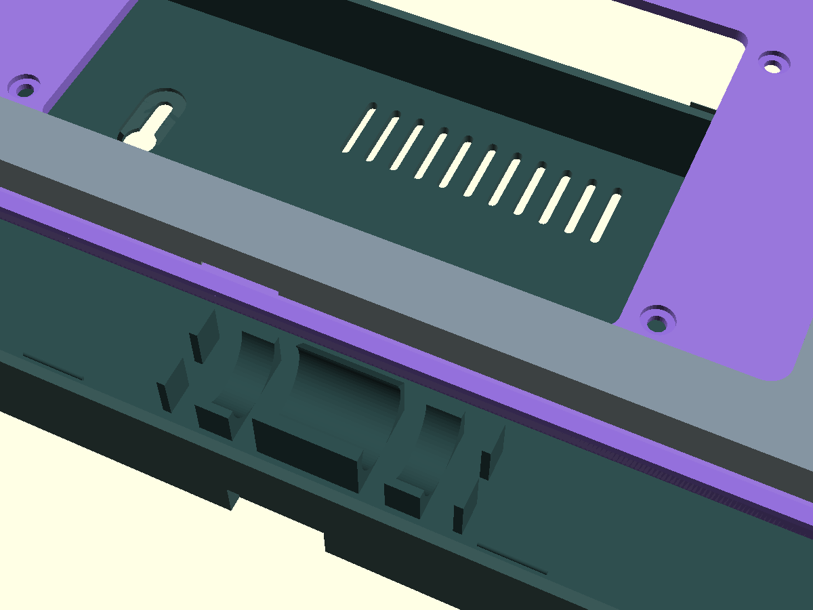
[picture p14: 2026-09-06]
3D_Print_Case/front_true_face.png

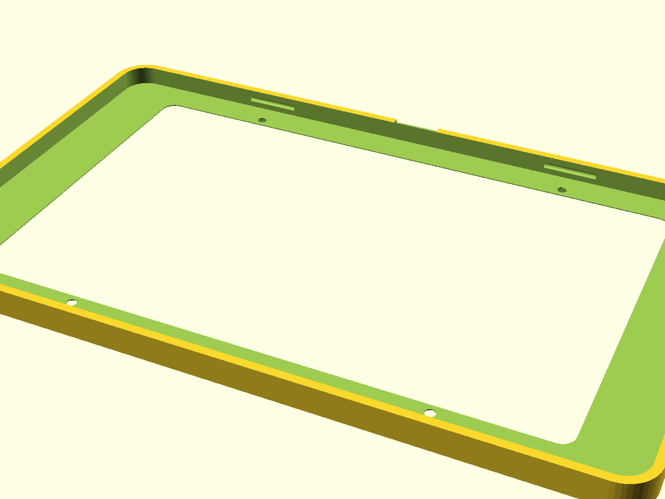
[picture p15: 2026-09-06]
3D_Print_Case/front_inside_new.png

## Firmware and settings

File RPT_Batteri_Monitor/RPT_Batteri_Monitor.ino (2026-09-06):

// =============================================================================
// PROJEKT : RPT-Batterimonitor med Waveshare ESP32-S3-Touch-LCD-7 (Rev 1.2)
// VERSION : v1.6.4 (ST7262 Centered Porches, Pylontech RS485 Protocol Fixed)
// DATO/TID: 2026-09-06 20:05:00
// =============================================================================

#include <Arduino.h>
#include "board_config.h"
#include "wifi_config.h"
#include "battery_data.h"
#include "can_receiver.h"
#include "sd_logger.h"
#include "ui.h"
#include "deye_bms_decoder.h"
#include "web_server.h"
#include "board_battery.h"
#include "system_config.h"
#include "rs485_battery_manager.h"
#include "deye_can_gateway.h"

// Tracking variables for periodic serial output
static uint32_t last_serial_stats_ms = 0;
static uint32_t last_watchdog_ms = 0;
static uint32_t last_heartbeat_ms = 0;

void printStartupBanner() {
    LOG_PRINTLN("\n================================================================================");
    LOG_PRINTLN("   RPT & ROSEN BATTERY STORAGE DASHBOARD - PHASE 2 (MULTIDROP RS485)");
    LOG_PRINTLN("   Target Hardware: Waveshare ESP32-S3-Touch-LCD-7 (Rev 1.2)");
    LOG_PRINTLN("   Screen: 7.0 inch IPS RGB (800x480) - ST7262 Driver");
    LOG_PRINTLN("   Firmware Date  : 2026-09-06 20:05:00 (v1.6.4 ST7262 Centering + Pylon 0x42 Fix)");
    LOG_PRINTF( "   Compile Time   : %s %s\n", __DATE__, __TIME__);
    LOG_PRINTLN("================================================================================");
    LOG_PRINTF("   CAN Controller : ESP32-S3 TWAI (TX: GPIO%d, RX: GPIO%d)\n",
                  BOARD_CAN_TX_PIN, BOARD_CAN_RX_PIN);
    LOG_PRINTF("   RS485 Port     : UART1 (TX: GPIO%d, RX: GPIO%d, 9600 baud Multidrop)\n",
                  BOARD_RS485_TX_PIN, BOARD_RS485_RX_PIN);
    LOG_PRINTLN("   Deye Gateway   : Pylontech CAN Emulation to Inverter (0x351/355/356/359/35C/35E)");
#if BOARD_CAN_POINT_TO_POINT
    LOG_PRINTLN("   CAN Mode       : POINT-TO-POINT (Hardware ACK active)");
    LOG_PRINTLN("   Termination    : Jumper 13 MUST BE INSTALLED/ON (120 Ohm bus termination)");
#else
    LOG_PRINTLN("   CAN Mode       : LISTEN-ONLY (Passive, No Transmit, No ACK)");
    LOG_PRINTLN("   Termination    : Jumper 13 MUST BE REMOVED/OFF (External bus already terminated)");
#endif
    LOG_PRINTF("   Baud Rate      : %d kbit/s\n", BOARD_CAN_DEFAULT_BAUDRATE / 1000);
    LOG_PRINTF("   LiPo ADC       : GPIO %d (Sensor AD Pin 2 to TP1, Ratio: %.2fx)\n",
                  (int)BOARD_LIPO_ADC_PIN, BOARD_LIPO_DIVIDER_RATIO);
    LOG_PRINTLN("   Multiplexer    : CH422G EXIO5 = HIGH (CAN_SEL routed to TJA1051)");
    LOG_PRINTLN("   Serial Port    : USB-C port UART1 (CH343) at 115200 baud");
    LOG_PRINTLN("================================================================================\n");
}

void printSerialIdStatistics() {
    ScannerOverview overview;
    CanReceiver::getInstance().getOverview(overview);

    CanIdStats stats[MAX_TRACKED_CAN_IDS];
    size_t count = CanReceiver::getInstance().getIdStatistics(stats, MAX_TRACKED_CAN_IDS);

    LOG_PRINTLN("\n--- [BATTERY TELEMETRY & CAN REPORT] -----------------------------------------");
    LOG_PRINTF("Total Frames: %lu | Rate: %.1f fps | Active IDs: %u | Bus Errors: %lu | SD: %s\n",
                  (unsigned long)overview.total_packets,
                  overview.packets_per_sec,
                  (unsigned int)overview.active_ids_count,
                  (unsigned long)overview.bus_error_count,
                  overview.sd_card_mounted ? overview.sd_filename : "No SD card");

#include "system_config.h"

    BatteryData bData;
    if (DeyeBmsDecoder::getInstance().getBatteryData(bData)) {
        const char* mName = SystemConfig::getInstance().getBrandName(SystemConfig::getInstance().getMaster());
        const char* sName = SystemConfig::getInstance().getBrandName(SystemConfig::getInstance().getSlave());
        LOG_PRINTF(">>> BATTERY STATUS: SOC: %u%% | SOH: %u%% | Volt: %.2fV | Curr: %+.1fA | Power: %+.2fkW | Temp: %.1fC\n",
                   bData.soc_percent, bData.soh_percent, bData.voltage_V, bData.current_A, bData.power_W / 1000.0f, bData.temperature_C);
        LOG_PRINTF(">>> MASTER (%s): %+.1fA (%+.2fkW) | SLAVE (%s): %s\n",
                   mName, bData.pack1_current_A, bData.pack1_power_W / 1000.0f,
                   sName, bData.pack2_online ? "ONLINE" : "OFFLINE");
        LOG_PRINTF("    Cells: Min %.3fV, Max %.3fV (dV: %.0fmV) | Capacity: %uAh | Modules: %u\n",
                   bData.minCellVoltage_V, bData.maxCellVoltage_V, bData.cellDelta_mV, bData.totalCapacity_Ah, bData.moduleCount);
        LOG_PRINTF("    Limits: MaxChg %.1fA, MaxDchg %.1fA, ChgV %.2fV, Cutoff %.2fV\n",
                   bData.chargeCurrentLimit_A, bData.dischargeCurrentLimit_A, bData.chargeVoltageLimit_V, bData.dischargeCutoffVoltage_V);
        LOG_PRINTF(">>> RS485 MULTIDROP: %s | RX: %lu frames, Err: %lu | Active Proto: %s\n",
                   bData.rs485_online ? "ONLINE" : "POLLING...",
                   (unsigned long)bData.rs485_rx_count,
                   (unsigned long)bData.rs485_err_count,
                   Rs485BatteryManager::getInstance().getActiveProtocol() == RS485_PROTO_MODBUS_RTU ? "Modbus RTU" :
                   (Rs485BatteryManager::getInstance().getActiveProtocol() == RS485_PROTO_PYLON_ASCII ? "Pylontech ASCII" : "Auto-Detecting"));
        LOG_PRINTF("    Pack 1 [%s]: %s (%.1fA, %u%% SOC, Min: %.3fV, Max: %.3fV)\n",
                   bData.pack1_name, bData.pack1_online ? "ONLINE" : "OFFLINE",
                   bData.pack1_current_A, bData.pack1_soc_percent, bData.pack1_minV, bData.pack1_maxV);
        LOG_PRINTF("    Pack 2 [%s]: %s (%.1fA, %u%% SOC, Min: %.3fV, Max: %.3fV)\n",
                   bData.pack2_name, bData.pack2_online ? "ONLINE" : "OFFLINE",
                   bData.pack2_current_A, bData.pack2_soc_percent, bData.pack2_minV, bData.pack2_maxV);
        LOG_PRINTF(">>> DEYE CAN GATEWAY: %s (TX Frames to Inverter: %lu)\n",
                   DeyeCanGateway::getInstance().isEnabled() ? "ACTIVE" : "STANDBY",
                   (unsigned long)DeyeCanGateway::getInstance().getTxCount());
    }

    // Report ESP32 Onboard LiPo Battery (Option A via TP1 & GPIO 6)
    LipoBatteryStatus lipo = BoardBattery::getInstance().getStatus();
    if (lipo.connected) {
        LOG_PRINTF(">>> ESP32 LIPO BATTERY: %.1fV (%u%%) [Option A: TP1 -> GPIO %d, Ratio: %.2fx]\n",
                   lipo.voltage_V, lipo.soc_percent, (int)BOARD_LIPO_ADC_PIN, BOARD_LIPO_DIVIDER_RATIO);
    } else {
        LOG_PRINTLN(">>> ESP32 LIPO BATTERY: N/A (Disconnected or < 2.0V)");
    }

    LOG_PRINTLN("--------------------------------------------------------------------------------");
    LOG_PRINTLN("CAN-ID   TYPE  DLC   COUNT    INTERVAL   LAST PAYLOAD (HEX)");
    LOG_PRINTLN("--------------------------------------------------------------------------------");

    if (count == 0) {
        LOG_PRINTLN("  (No CAN traffic observed yet. Check wiring: RJ45 Pin 4=CAN-H, Pin 5=CAN-L)");
    } else {
        for (size_t i = 0; i < count; i++) {
            const CanIdStats& s = stats[i];
            char payloadStr[32] = "";
            for (int b = 0; b < s.dlc && b < 8; b++) {
                char hex[5];
                snprintf(hex, sizeof(hex), "%02X ", s.last_data[b]);
                strcat(payloadStr, hex);
            }

            LOG_PRINTF("0x%03X%s  %s   %u   %6lu   %5lums    %s\n",
                          (unsigned int)s.id,
                          (s.id < 0x100 ? " " : ""),
                          s.extended ? "EXT" : "STD",
                          s.dlc,
                          (unsigned long)s.count,
                          (unsigned long)s.interval_ms,
                          payloadStr);
        }
    }
    LOG_PRINTLN("--------------------------------------------------------------------------------\n");
}

void setup() {
    // 1. Initialize Serial Communication for debug & data logging
    Serial.begin(115200);
#if ARDUINO_USB_CDC_ON_BOOT
    Serial0.begin(115200); // Hardware UART0 on GPIO 43/44 (CH343 USB-to-UART bridge)
#endif

    delay(200);

    LOG_PRINTLN("\n\n================================================================================");
    LOG_PRINTF( ">>> ESP32-S3 RPT BATTERY MONITOR - COMPILED: %s %s (v1.6.2) <<<\n", __DATE__, __TIME__);
    printStartupBanner();

    // 0. Initialize Persistent System Configuration (Master/Slave settings)
    SystemConfig::getInstance().begin();

    // 1. Initialize Board LiPo Battery ADC (Option A via TP1 & GPIO 6)
    LOG_PRINTLN("[BOOT 1/6] Initializing Board LiPo Battery ADC (Option A: GPIO 6)...");
    BoardBattery::getInstance().begin();

    // 2. Initialize Protocol Decoder
    LOG_PRINTLN("[BOOT 2/6] Initializing Protocol Decoder...");
    DeyeBmsDecoder::getInstance().begin();

    // 3. Initialize WiFi FIRST (Fast 1-2 sec connection before display starts!)
    // By connecting WiFi before screen initialization, the ST7262 never experiences
    // RF power bursts, channel hopping, or Flash NVS locks during display startup.
    LOG_PRINTLN("[BOOT 3/6] Initializing WiFi & Web Server Subsystem (Fast-Scan)...");
    BatteryWebServer::getInstance().begin();

    // 4. Initialize UI & Board Hardware
    // Sets up Wire on SDA=8/SCL=9, pulses LCD_RST, turns on Backlight, and starts the ST7262 display.
    LOG_PRINTLN("[BOOT 4/6] Initializing Board Hardware, I2C, and ST7262 RGB Display...");
    if (!UIManager::getInstance().begin()) {
        LOG_PRINTLN("[BOOT WARNING] UI / Display initialization reported an issue.");
    } else {
        LOG_PRINTLN("[BOOT OK] Display initialized successfully!");
    }

    // 5. Initialize MicroSD Card Logger (after I2C/CH422G is ready)
    LOG_PRINTLN("[BOOT 5/6] Initializing MicroSD Logger...");
    SdLogger::getInstance().begin();

    // 6. Initialize TWAI CAN Receiver (500 kbit/s, Point-to-Point / Hardware ACK)
    LOG_PRINTLN("[BOOT 6/8] Activating CAN Mode (CH422G EXIO5 = HIGH) & TWAI Receiver...");
    UIManager::getInstance().setCanMode(true);
    delay(50);
    if (!CanReceiver::getInstance().begin(BOARD_CAN_DEFAULT_BAUDRATE)) {
        LOG_PRINTLN("[BOOT FATAL] Failed to start CAN Receiver! Check pins and TWAI driver.");
    } else {
        LOG_PRINTLN("[BOOT OK] CAN Receiver listening!");
    }

    // 7. Initialize Multidrop RS485 Battery Manager (UART1 on GPIO 15/16)
    LOG_PRINTLN("[BOOT 7/8] Initializing Multidrop RS485 Battery Poller (Pack 1 & 2)...");
    Rs485BatteryManager::getInstance().begin(9600);

    // 8. Initialize Deye CAN Gateway (Transmits Pylontech telemetry frames to inverter)
    LOG_PRINTLN("[BOOT 8/8] Initializing Deye CAN Gateway (Pylontech Inverter Protocol)...");
    DeyeCanGateway::getInstance().begin();

    LOG_PRINTLN("\n[SYSTEM READY] All subsystems started. Polling RS485 & Gateway active.\n");
    last_serial_stats_ms = millis();
    last_watchdog_ms = millis();
    last_heartbeat_ms = millis();
}

void loop() {
    CanFrameRaw frame;

    // Drain up to 25 frames non-blocking (0 wait) per cycle to prevent loop starvation and watchdog resets
    uint8_t processedFrames = 0;
    while (processedFrames < 25 && CanReceiver::getInstance().getNextFrame(frame, 0)) {
        processedFrames++;
        // 1. Write to MicroSD card CSV file
        SdLogger::getInstance().logFrame(frame);

        // 2. Pass to decoder hook
        DeyeBmsDecoder::getInstance().decodeFrame(frame);

        // 3. Print individual frame to Serial Monitor in real-time (non-blocking)
        if (Serial.availableForWrite() >= 96) {
            char dataHex[32] = "";
            for (int i = 0; i < frame.dlc && i < 8; i++) {
                char b[5];
                snprintf(b, sizeof(b), "%02X ", frame.data[i]);
                strcat(dataHex, b);
            }

            ScannerOverview overview;
            CanReceiver::getInstance().getOverview(overview);

            LOG_PRINTF("[%7lums] ID: 0x%03X (%s) DLC: %d Data: %-24s [Total: %lu]\n",
                          (unsigned long)frame.timestamp_ms,
                          (unsigned int)frame.id,
                          frame.extended ? "EXT" : "STD",
                          frame.dlc,
                          dataHex,
                          (unsigned long)overview.total_packets);
        }
    }

    uint32_t now = millis();

    // Heartbeat every 2 seconds to prove board is alive and report physical bus state
    if (now - last_heartbeat_ms >= 2000) {
        ScannerOverview ov;
        CanReceiver::getInstance().getOverview(ov);
        const char* stateStr = "RUNNING";
        if (ov.twai_state == 0) stateStr = "STOPPED";
        else if (ov.twai_state == 2) stateStr = "BUS_OFF";
        else if (ov.twai_state == 3) stateStr = "RECOVERING";

        LOG_PRINTF("[HEARTBEAT %lus] State: %s | Frames: %lu | Bus Errors: %lu | REC: %lu | TEC: %lu\n",
                   (unsigned long)(now / 1000),
                   stateStr,
                   (unsigned long)ov.total_packets,
                   (unsigned long)ov.bus_error_count,
                   (unsigned long)ov.rx_error_counter,
                   (unsigned long)ov.tx_error_counter);
        last_heartbeat_ms = now;
    }

    // Periodic statistics report to Serial every 5 seconds
    if (now - last_serial_stats_ms >= 5000) {
        printSerialIdStatistics();
        last_serial_stats_ms = now;
    }

    // Watchdog check for protocol decoder
    if (now - last_watchdog_ms >= 1000) {
        DeyeBmsDecoder::getInstance().checkWatchdog(5000);
        last_watchdog_ms = now;
    }

    // Service RS485 Multidrop Battery Poller
    Rs485BatteryManager::getInstance().update();

    // Service Deye CAN BMS Gateway (Transmits heartbeats to Deye inverter)
    DeyeCanGateway::getInstance().update();

    // Handle Web Server client requests & background WiFi reconnect
    BatteryWebServer::getInstance().loop();

    // Sample Board LiPo Battery (rate-limited internally to 500ms)
    BoardBattery::getInstance().update();

    // Yield to FreeRTOS scheduler
    vTaskDelay(pdMS_TO_TICKS(5));
}

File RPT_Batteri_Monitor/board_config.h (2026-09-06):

#pragma once

// =============================================================================
// PROJEKT : RPT-Batterimonitor med Waveshare ESP32-S3-Touch-LCD-7 (Rev 1.2)
// VERSION : v1.6.4 (ST7262 Centered Porches, Pylontech RS485 Protocol Fixed)
// DATO/TID: 2026-09-06 20:05:00
// =============================================================================

#include <Arduino.h>
#include "driver/gpio.h"

/**
 * ============================================================================
 * Hardware Pin Definitions for Waveshare ESP32-S3-Touch-LCD-7 (Rev 1.2)
 * Display: 7.0 inch 800x480 RGB LCD
 * ============================================================================
 */

// -----------------------------------------------------------------------------
// CAN Bus Interface (TWAI)
// Note: On the 7" board, GPIO 19 & 20 are routed to the onboard TJA1051 CAN
// transceiver via an FSUSB42 multiplexer controlled by CH422G EXIO5.
// CH422G EXIO5 MUST BE PULLED HIGH to enable CAN mode!
//
// Point-to-Point Mode:
// Direct dedicated connection to RPT battery CAN port (no inverter on CAN bus).
// In this mode, ESP32 must provide hardware ACK bits so the battery's CAN
// controller does not halt with ACK errors. Firmware transmits zero data frames.
// -----------------------------------------------------------------------------
#define BOARD_CAN_TX_PIN            GPIO_NUM_20
#define BOARD_CAN_RX_PIN            GPIO_NUM_19
#define BOARD_CAN_DEFAULT_BAUDRATE  500000      // 500 kbit/s (standard Deye/Pylontech)
#define BOARD_CAN_POINT_TO_POINT    true        // Direct point-to-point to battery CAN

// -----------------------------------------------------------------------------
// I2C Interface (Shared: CH422G I/O Expander, GT911 Touch, PCF85063 RTC)
// -----------------------------------------------------------------------------
#define BOARD_I2C_SDA_PIN           GPIO_NUM_8
#define BOARD_I2C_SCL_PIN           GPIO_NUM_9
#define BOARD_I2C_FREQ_HZ           100000      // 100 kHz Standard-Mode (Required for CH422G)

// CH422G I2C 7-bit Addresses:
// 0x48 >> 1 = 0x24 (WR-SET: system parameter register)
// 0x46 >> 1 = 0x23 (WR-OC: open drain output register)
// 0x70 >> 1 = 0x38 (WR-IO: general purpose output register EXIO0-7)
// 0x4D >> 1 = 0x26 (RD-IO: general purpose input register)
#define CH422G_I2C_ADDR_WR_SET      0x24
#define CH422G_I2C_ADDR_WR_OC       0x23
#define CH422G_I2C_ADDR_WR_IO       0x38
#define CH422G_I2C_ADDR_RD_IO       0x26

// CH422G EXIO Pin Mask Assignments on ESP32-S3-Touch-LCD-7
#define CH422G_EXIO1_TP_RST         (1 << 1)    // GT911 Touch reset (active low)
#define CH422G_EXIO2_LCD_BL         (1 << 2)    // LCD Backlight enable (active high)
#define CH422G_EXIO3_LCD_RST        (1 << 3)    // LCD Reset (active low)
#define CH422G_EXIO4_SD_CS          (1 << 4)    // MicroSD Chip Select (active low)
#define CH422G_EXIO5_CAN_SEL        (1 << 5)    // High = CAN Mode, Low = USB Mode

// -----------------------------------------------------------------------------
// MicroSD Card (TF Card) Interface (SPI)
// -----------------------------------------------------------------------------
#define BOARD_SD_MOSI_PIN           GPIO_NUM_11
#define BOARD_SD_SCK_PIN            GPIO_NUM_12
#define BOARD_SD_MISO_PIN           GPIO_NUM_13
#define BOARD_SD_CS_PIN             -1          // Managed via CH422G EXIO4

// -----------------------------------------------------------------------------
// Touch Screen (GT911)
// -----------------------------------------------------------------------------
#define BOARD_TOUCH_IRQ_PIN         GPIO_NUM_4
#define BOARD_TOUCH_I2C_ADDR        0x5D        // Default address (or 0x14)

// -----------------------------------------------------------------------------
// RS485 Interface (U6: SP3485EN Transceiver & S1 Auto-Direction Transistor)
// Hardware: U6 Pin 1 (RO) -> GPIO 15 (RX) | S1 Base -> GPIO 16 (TX)
// -----------------------------------------------------------------------------
#define BOARD_RS485_TX_PIN          GPIO_NUM_16
#define BOARD_RS485_RX_PIN          GPIO_NUM_15

// -----------------------------------------------------------------------------
// ESP32-S3 LiPo Battery Voltage Sensing (Option A: TP1 to Sensor AD / GPIO 6)
// Hardware Voltage Divider: R18 = 200k (1%), R19 = 100k (1%)
// Voltage Multiplier: (200k + 100k) / 100k = 3.00
// Sensor Connector J8: Pin 1 = 3V3, Pin 2 = AD (GPIO 6), Pin 3 = GND
// Jumper wire: J8 Pin 2 (AD) connected to TP1 test point on PCB
// -----------------------------------------------------------------------------
#define BOARD_LIPO_ADC_PIN          GPIO_NUM_6
#define BOARD_LIPO_DIVIDER_RATIO    3.00f       // Hardware ratio = (200k + 100k) / 100k
#define BOARD_LIPO_MIN_CONNECTED_V  2.00f       // Below 2.0V considered disconnected
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

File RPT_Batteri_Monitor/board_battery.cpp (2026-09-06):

// =============================================================================
// PROJEKT : RPT-Batterimonitor med Waveshare ESP32-S3-Touch-LCD-7 (Rev 1.2)
// MODUL   : board_battery.cpp
// DATO/TID: 2026-09-06 19:32:00
// =============================================================================

#include "board_battery.h"

BoardBattery& BoardBattery::getInstance() {
    static BoardBattery instance;
    return instance;
}

BoardBattery::BoardBattery()
    : _filtered_voltage(0.0f),
      _last_read_ms(0),
      _mux(portMUX_INITIALIZER_UNLOCKED)
{
    _status.voltage_V = 0.0f;
    _status.soc_percent = 0;
    _status.connected = false;
}

BoardBattery::~BoardBattery() {
}

void BoardBattery::begin() {
    pinMode(BOARD_LIPO_ADC_PIN, INPUT);
    analogReadResolution(12);
    analogSetAttenuation(ADC_11db);

    // Initial reading to populate status immediately on boot
    update();

    LOG_PRINTF("[LIPO] ADC initialized on GPIO %d (Divider ratio: %.2fx)\n",
               (int)BOARD_LIPO_ADC_PIN, BOARD_LIPO_DIVIDER_RATIO);
    if (_status.connected) {
        LOG_PRINTF("[LIPO] Detected battery: %.2fV (%u%% SOC)\n",
                   _status.voltage_V, _status.soc_percent);
    } else {
        LOG_PRINTLN("[LIPO] No battery detected (V < 2.0V or jumper wire TP1->AD not installed).");
    }
}

void BoardBattery::update() {
    uint32_t now = millis();
    // Rate-limit reading to twice per second (500ms) to conserve CPU and avoid jitter
    if (_last_read_ms != 0 && (now - _last_read_ms < 500)) {
        return;
    }
    _last_read_ms = now;

    // Sample ADC 16 times to average out high-frequency electrical and RF noise
    uint32_t sumMv = 0;
    for (int i = 0; i < 16; i++) {
        sumMv += analogReadMilliVolts(BOARD_LIPO_ADC_PIN);
    }
    float pinVolts = (sumMv / 16.0f) / 1000.0f;
    float rawVoltage = pinVolts * BOARD_LIPO_DIVIDER_RATIO;

    // Check if connected (battery present and jumper wire TP1 -> AD installed)
    bool isConnected = (rawVoltage >= BOARD_LIPO_MIN_CONNECTED_V);

    if (isConnected) {
        // Exponential moving average filter (alpha = 0.20) for rock-solid zero-jitter display
        if (_filtered_voltage < 1.0f) {
            _filtered_voltage = rawVoltage;
        } else {
            _filtered_voltage = (_filtered_voltage * 0.80f) + (rawVoltage * 0.20f);
        }
    } else {
        _filtered_voltage = 0.0f;
    }

    uint8_t pct = isConnected ? voltageToPercent(_filtered_voltage) : 0;

    portENTER_CRITICAL(&_mux);
    _status.voltage_V = isConnected ? _filtered_voltage : 0.0f;
    _status.soc_percent = pct;
    _status.connected = isConnected;
    portEXIT_CRITICAL(&_mux);
}

LipoBatteryStatus BoardBattery::getStatus() {
    portENTER_CRITICAL(&_mux);
    LipoBatteryStatus st = _status;
    portEXIT_CRITICAL(&_mux);
    return st;
}

void BoardBattery::getFormattedString(char* buf, size_t bufSize) {
    if (!buf || bufSize == 0) return;
    LipoBatteryStatus st = getStatus();
    if (st.connected) {
        snprintf(buf, bufSize, "Lipo Bat: %.1fV (%u%%)", st.voltage_V, st.soc_percent);
    } else {
        snprintf(buf, bufSize, "Lipo Bat: N/A");
    }
}

uint8_t BoardBattery::voltageToPercent(float v) {
    if (v >= 4.20f) return 100;
    if (v <= 3.30f) return 0;

    // Piecewise linear interpolation for standard 1S 3.7V Li-ion / LiPo discharge profile
    static const struct {
        float v;
        uint8_t pct;
    } curve[] = {
        { 4.20f, 100 },
        { 4.10f,  90 },
        { 4.00f,  80 },
        { 3.90f,  70 },
        { 3.82f,  55 },
        { 3.75f,  40 },
        { 3.70f,  30 },
        { 3.65f,  20 },
        { 3.55f,  10 },
        { 3.40f,   3 },
        { 3.30f,   0 }
    };
    constexpr size_t numPoints = sizeof(curve) / sizeof(curve[0]);

    for (size_t i = 0; i < numPoints - 1; i++) {
        if (v >= curve[i + 1].v) {
            float rangeV = curve[i].v - curve[i + 1].v;
            float frac = (v - curve[i + 1].v) / rangeV;
            uint8_t rangePct = curve[i].pct - curve[i + 1].pct;
            return curve[i + 1].pct + (uint8_t)(frac * rangePct + 0.5f);
        }
    }
    return 0;
}

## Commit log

2026-09-03 Initial commit: Fase 1 CAN-scanner til Waveshare ESP32-S3-Touch-LCD-7 Rev 1.2
2026-09-04 Organiser projektet i Arduino sketch-mappe RPT_Batteri_Monitor for fuld Arduino IDE kompatibilitet
2026-09-04 Sæt I2C til 100 kHz med 50ms timeout for CH422G for at forhindre hængning i Wire.endTransmission
2026-09-04 Brug native ESP-IDF driver/i2c.h for CH422G med timeout og build v1.0.3
2026-09-04 Løs driver_ng konflikt ved brug af ren Wire på 100kHz og opdater til v1.0.4
2026-09-04 Fix ST7262 LCD reset sequence, clock polarity, bounce buffer, and dual-serial routing (v1.0.5)
    [RPT_Batteri_Monitor.ino, board_config.h, sd_logger.cpp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]
2026-09-05 feat: Implement Phase 2 graphical battery storage dashboard and Pylontech decoder
2026-09-05 fix: Update boot banner to dynamic compile timestamp and add live uptime/RX latency to UI headers
    [RPT_Batteri_Monitor.ino, ui.cpp]
2026-09-05 fix: Add full screen clear with memset on redraw to prevent margin artifacts and ghosting
    [ui.cpp]
2026-09-05 feat: Fix screen bleed with full black wipe, redesign Dashboard cards, and implement 32-cell dual-pack view (Rosen+RPT)
    [ui.cpp]
2026-09-05 feat: Web server, LiPo battery monitor, >100A UI layout, zero-flicker rendering, and multi-core stability fixes
    - Added WiFi Web Server with real-time responsive dashboard, 4x cell voltage bars, and JSON REST API (/api/data, /api/scanner)
    - Added 3.7V LiPo battery monitor on GPIO 4 (ADC) with voltage display and SOC estimation
    - Redesigned Page 1 Hero cards for SOC, Storage Power, Bank Voltage, and Current with dynamic font scaling for >100A discharge
    - Replaced whole-screen clears on Page 2 and 3 with zero-flicker in-place and differential rendering
    - Confined capacitive touch interaction strictly to bottom navigation buttons (Y >= 420)
    - Resolved ESP32-S3 crash vectors: increased ui_task s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
    [RPT_Batteri_Monitor.ino, board_battery.cpp, board_config.h]
2026-09-06 fix: 10MHz PCLK, ST7262 porches to prevent vertical drift, zero-flicker Page 1 caching, and removal of Cache_WriteBack_All (v1.5.0)
    [RPT_Batteri_Monitor.ino, board_config.h, ui.cpp]
2026-09-06 fix: Restore 16MHz PCLK and proven ST7262 timings to exit color shift test mode (v1.5.1)
    [RPT_Batteri_Monitor.ino, board_config.h]
2026-09-06 fix: Restore Page 1 IP address display and invalidate header cache on redraw (v1.5.2)
    [RPT_Batteri_Monitor.ino, board_config.h, ui.cpp]
2026-09-06 fix: Eliminate vertical screen drift via 20L bounce buffer, 15MHz PCLK, IRAM VSYNC callback, and automatic GDMA re-sync (v1.5.3)
    [RPT_Batteri_Monitor.ino, board_config.h, ui.cpp]
2026-09-06 feat: Add custom 3D printable wall-mount enclosure with flush front bezel, snap-fit closure, and port cutouts for Waveshare 7-inch LCD
    [Waveshare7_Back_Case.stl, Waveshare7_Front_Bezel.stl, Waveshare7_Full_Enclosure.scad]
2026-09-06 feat: Add integrated 18650 snap battery holder, universal side port cutouts, and 100% manifold STL meshes
    [Waveshare7_Back_Case.stl, Waveshare7_Front_Bezel.stl, Waveshare7_Full_Enclosure.scad]
2026-09-06 fix: Remove right-side port cutouts, leaving only left-side USB/SD openings on back case
    [Waveshare7_Back_Case version 1.3mf, Waveshare7_Back_Case.stl, Waveshare7_Front_Bezel.stl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]
2026-09-06 Add display clamp brackets and proper rear mounting pillars to 3D print enclosure
    [Waveshare7_Back_Case.stl, Waveshare7_Clamp_Brackets.stl, Waveshare7_Front_Bezel.stl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]
2026-09-06 Implement 3-part enclosure architecture: Front Bezel, Mellemstykke display carrier, and Back Case
    [Waveshare7_Back_Case.stl, Waveshare7_Clamp_Brackets.stl, Waveshare7_Front_Bezel.stl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]
2026-09-06 Fix front bezel: 170x100mm cutout, firmly anchored corner bosses away from hole; remove 4 stag in back case
    [Waveshare7_Back_Case.stl, Waveshare7_Front_Bezel.stl, Waveshare7_Full_Enclosure.scad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]
2026-09-06 Make enclosure 228mm wide (+20mm for USB clearance) and ensure 2.5mm solid shelf for front undersænkning
    [Waveshare7_Back_Case.stl, Waveshare7_Front_Bezel.stl, Waveshare7_Full_Enclosure.scad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]
2026-09-06 feat: Multidrop RS485 battery poller, ST7262 centering, Pylontech 0x42 decoding & 3D enclosure (v1.6.4 - 2026-09-06 20:05:00)
    [Waveshare7_Back_Case FINAL top og mellem.3mf, Waveshare7_Back_Case version 2.3mf, Waveshare7_Back_Case version 3.3mf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]
